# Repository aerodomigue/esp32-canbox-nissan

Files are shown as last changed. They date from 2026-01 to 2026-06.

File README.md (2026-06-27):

# ESP32 CANBox Bridge

> **Available Languages:** [Français](README.fr.md) | **English**

<p align="center">
  Assembled unit with OBD-II connector
  3D printed enclosure
</p>

<p align="center">
  Dynamic guidelines in action
  <br>
  <em>Dynamic reverse camera guidelines working with the CAN bridge</em>
</p>

This project is a **universal CAN bridge** that connects any vehicle to an Android head unit. The ESP32 reads CAN bus frames via the OBD-II port and translates them to protocols understood by Android head units (Toyota RAV4, Raise, etc.).

The project started as a custom solution for the **Nissan Juke F15**, but has since evolved into a generic, multi-vehicle platform.

**Key features:**
- **Multi-vehicle support** — Vehicle-specific CAN mappings are defined in JSON configuration files, making it easy to add support for new cars
- **Protocol translation** — Converts manufacturer-specific CAN data to head unit protocols (Toyota RAV4, Raise/RZC)
- **No recompilation needed** — Switch vehicles, adjust calibration via USB commands, or embed model-specific calibration directly in the vehicle JSON preset (`vehicleParams`)

> **Important:** In your head unit settings, configure the CAN protocol as **"Toyota RAV4"** for this to work.

> **Required App:** Use **[ESP32 CANBox Manager](https://github.com/aerodomigue/esp32-canbox-manager)** (Android) to configure, calibrate, and update the firmware via USB.

---

## Features

- **Real-time data translation** from Nissan CAN to Toyota RAV4 protocol
- **Steering wheel angle** for reverse camera guidelines
- **Dashboard data**: RPM, speed, battery voltage, temperature, fuel level
- **Door status** with automatic updates on change
- **Safety systems**: Hardware watchdog, CAN error monitoring, timeout protection

### Feature Status

| Feature | Status | Notes |
| --- | --- | --- |
| Engine RPM | ✅ Working | |
| Vehicle Speed | ✅ Working | |
| Fuel Tank Level | ✅ Working | Calibrated for Juke F15 (45L tank) |
| Battery Voltage | ✅ Working | |
| Steering / Dynamic Guidelines | ✅ Working | Calibrated for Juke F15 |
| Door Status | ✅ Working | All 4 doors + trunk |
| Indicators | ✅ Working | Left/right turn signals |
| Lights | ✅ Working | Headlights, high beam, parking lights |
| Handbrake | 📋 Planned | CAN data not yet extracted |
| External Temperature | 📋 Planned | CAN data not yet extracted |
| Instant Fuel Consumption | ✅ Working | From CAN 0x580 |
| Average Fuel Consumption | ✅ Working | From CAN 0x580 |
| Distance to Empty | ✅ Working | From CAN 0x54C |

> **Note:** Documentation for the Raise/Toyota RAV4 protocol used by Android head units is scarce. Some features are still being reverse-engineered due to lack of official protocol specifications.

See the **[Roadmap](ROADMAP.md)** for upcoming features.

---

## Hardware Requirements

### Bill of Materials (BOM)

| Component | Description | Link |
| --- | --- | --- |
| **ESP32-C3 SuperMini** | Microcontroller with native TWAI (CAN) | [AliExpress](https://fr.aliexpress.com/item/1005007479144456.html) |
| **SN65HVD230** | CAN Transceiver (3.3V) | [AliExpress](https://fr.aliexpress.com/item/1005009371955871.html) |
| **L7805CV** | 5V Voltage Regulator | [AliExpress](https://fr.aliexpress.com/item/1005005961287271.html) |
| **PCB Prototype Board** | 4x6cm perfboard | [AliExpress](https://fr.aliexpress.com/item/1005008880680070.html) |
| **Capacitor 25V 470µF** | Filtering capacitor | [AliExpress](https://fr.aliexpress.com/item/1005002075527957.html) |
| **PCB Terminal Block** | Screw terminals for wiring | [AliExpress](https://fr.aliexpress.com/item/1005006642865467.html) |
| **Fuse 1A** | Protection fuse | [AliExpress](https://fr.aliexpress.com/item/1005001756852562.html) |
| **OBD-II Plug** | CAN-H (pin 6), CAN-L (pin 14) | - |

### Power Supply Note

The ESP32 is powered via **USB from the Android head unit**.

**IMPORTANT - If using 12V power instead of USB:**
- ⚠️ **NEVER use permanent 12V** - it will drain your car battery when parked
- ✅ **Use ACC (accessory) 12V only** - it turns off with the ignition
- You'll need a voltage regulator (like the L7805CV in the BOM) to convert 12V to 5V
- ⚠️ **The current 12V circuit needs improvements**: It lacks reverse polarity protection (risk of damage if wired incorrectly) and proper noise filtering for alternator-generated electrical interference. Additional components (diode, capacitors, TVS diode) would be recommended for a robust 12V power supply.

**Why USB is recommended:**
1. **Automatic power management**: USB power from the head unit is only active when the head unit is on (ACC-controlled), preventing battery drain.
2. **Voltage stability**: Automotive 12V is unstable - it varies significantly during engine start (voltage drops), alternator charging (spikes up to 14.5V), and contains electrical noise. USB provides clean, regulated 5V power.

### Wiring Diagram

<p align="center">
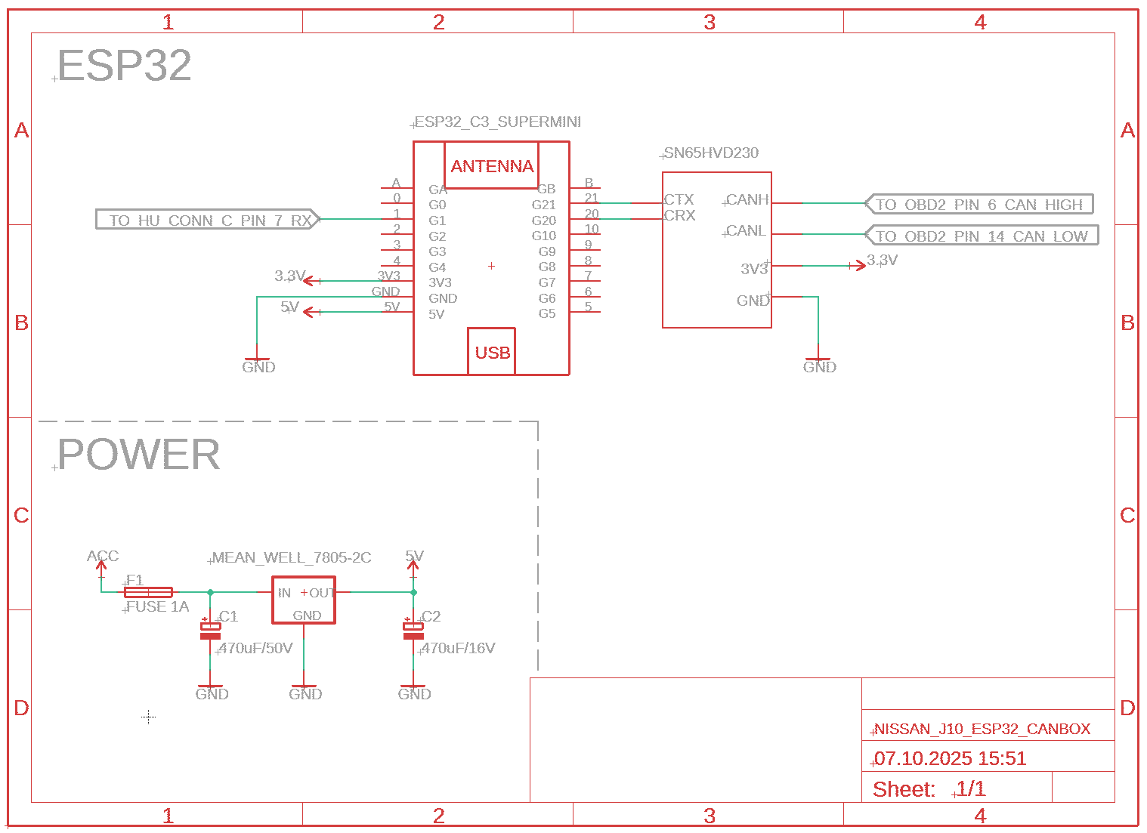
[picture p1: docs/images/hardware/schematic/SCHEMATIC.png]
Wiring schematic
  
  <br>
  <em>Schematic by Polihedron</em>
</p>

### Pinout

| Component | ESP32 Pin | Destination | Note |
| --- | --- | --- | --- |
| **SN65HVD230** | `3.3V` / `GND` | Power Supply | **Do not use 5V!** |
| | `GPIO 21` | CAN-TX | Output to CAN bus |
| | `GPIO 20` | CAN-RX | Input from CAN bus |
| **Head Unit** | `GPIO 5` (TX) | RX Wire (Radio harness) | UART 38400 baud |
| | `GPIO 6` (RX) | TX Wire (Radio harness) | Handshake responses |
| **Status LED** | `GPIO 8` | Internal LED | Visual status indicator |

### OBD-II Connection

The system connects to the vehicle via the **OBD-II diagnostic port**:

```
OBD-II Connector (looking at port)
┌─────────────────────────────┐
│  1   2   3   4   5   6   7  8  │
│                                 │
│  9  10  11  12  13  14  15  16 │
└─────────────────────────────┘

Pin 6  = CAN-H (High)
Pin 14 = CAN-L (Low)
Pin 16 = +12V Battery
Pin 4/5 = Ground
```

> **Note:** OBD-II ports have built-in termination resistors, so no additional resistor is needed on the SN65HVD230 module. If your module has a 120Ω resistor (R120), you can leave it or remove it - the bus will work either way.

### Electroheater (A/C) Connector Pinout — M25

The electroheater control unit uses connector **M25** (type TH16FW-NH, 16 pins). It carries the CAN bus and can be used as an alternative tap point.

```
Pin layout (front view):
┌─────────────────────────────────┐
│  1  2  3  4  5  6  7  8        │
│  9 10 11 12 13 14 15 16        │
└─────────────────────────────────┘
```

| Pin | Wire Color | Description |
| --- | --- | --- |
| 1 | L | **CAN-H** |
| 2 | B | Ground |
| 3 | SB | Ignition power supply |
| 4 | P | Electroheater control unit wake-up signal |
| 5 | R | Ambient temperature sensor ground |
| 9 | P | **CAN-L** |
| 10 | Y | Battery power supply |
| 12 | GR | Ambient temperature sensor signal |
| 13 | L | Ventilation system motor signal |
| 14 | Y | Electroheater relay control signal 1 |
| 15 | LG | Electroheater relay control signal 2 |
| 16 | P | Electroheater relay control signal 3 |

> Pins 6, 7, 8, 11 are not populated on this connector.

### About the Original CAN Box

The **original Raise/RZC CAN box** that came with the Android head unit is **kept installed**. It provides the **6V power supply for the reverse camera** and is still needed for that purpose.

The original box likely has CAN signal access on its connector, so it might be possible to tap the CAN bus from there instead of OBD-II. However, this was not tested - the OBD-II connection works well and is easier to install.

---

## USB Configuration (V2)

The device can be configured via USB serial without recompiling. Connect to the USB port and use a terminal at **115200 baud**.

### Available Commands

| Command | Description |
| --- | --- |
| `CFG LIST` | Show calibration parameters |
| `CFG SET <param> <value>` | Change a parameter |
| `CFG SAVE` | Save to flash (NVS) |
| `CAN STATUS` | Show CAN config status (MOCK/REAL mode) |
| `CAN LIST` | List vehicle config files |
| `CAN LOAD <file>` | Load a vehicle config |
| `CAN UPLOAD START/DATA/END` | Upload config via Base64 |
| `SYS INFO` | System information |
| `SYS DATA` | Live vehicle data |
| `HELP` | Full command list |

See **[USB Serial Protocol Documentation](docs/protocols/USB_SERIAL_PROTOCOL.md)** for complete details.

### Multi-Vehicle Support

Vehicle configurations are stored as JSON files on the device's filesystem. You can:
- Upload multiple vehicle configs (NissanJukeF15.json, ToyotaCorolla.json, etc.)
- Switch between vehicles with `CAN LOAD <file>`
- Use **Mock Mode** for testing without a vehicle

---

## Software Architecture

The system is designed to be 100% autonomous and resilient to vehicle electrical interference:

1. **[CAN Capture](docs/technical/CAN_CAPTURE.md)**: Decodes frames using JSON configuration and updates global variables
2. **[Radio Send](docs/technical/RADIO_SEND.md)**: Formats and transmits data to the head unit at multiple intervals (200ms for steering, 333ms for RPM, 500ms for speed, etc.)
3. **ConfigManager**: Persistent calibration storage (NVS). Vehicle JSON files can embed `vehicleParams` to supply model-specific defaults applied automatically on first load; user overrides via `CFG SET` are preserved across reboots on the same vehicle
4. **SerialCommand**: USB configuration interface
5. **Hardware Watchdog**: Automatic reboot if the program freezes for more than 5 seconds
6. **CAN Watchdog**: Forces reboot if no CAN data received for 30s while battery > 11V

---

## LED Status Codes

The LED (GPIO 8) provides quick diagnostics without requiring a PC connection:

| Pattern | Status | Meaning |
| --- | --- | --- |
| **Rapid flashing** | Normal | CAN data being received and processed |
| **Slow blink (500ms)** | Mock Mode | Running with simulated data |
| **Slow heartbeat (1s)** | Idle | System running, but CAN bus is silent |
| **Solid ON during boot** | Boot | System initializing |
| **No activity** | Error | System frozen or power issue |

---

## Hardware Photos

### PCB Assembly

<p align="center">
  PCB top view - components soldered
  PCB bottom view
</p>

*ESP32 with SN65HVD230 CAN transceiver soldered on perfboard*

---

## Installation & Setup

Setting up your ESP32 CANBox Bridge follows a simple two-step process:

### 1. Initial Firmware Flash
The ESP32 must be flashed with the firmware before installation. Use one of these methods:

- **Option A: Web Browser (Recommended)**
  Open **[web.esphome.io](https://web.esphome.io/)** in a Chrome-based browser.
  1. Download the **`all-firmware.bin`** from the [Latest Releases](https://github.com/aerodomigue/Nissan-canbus-headunit/releases). This single file contains the bootloader, partitions, and app.
  2. Connect your ESP32 to your computer via USB.
  3. Click **Connect**, then **Install** and select the `all-firmware.bin` file.

- **Option B: PlatformIO (Developers)**
  If you are working with the source code:
  ```bash
  pio run --target upload
  ```
  *Note: A `all-firmware.bin` is automatically generated in `.pio/build/` after each build.*

### 2. Configuration & Management
Once flashed, connect the ESP32 to your Android head unit's USB port. All further configuration is done via the companion app:

**[ESP32 CANBox Manager](https://github.com/aerodomigue/esp32-canbox-manager)** (Android App)
- **Select Vehicle**: Load the specific `.json` config for your car.
- **Calibrate**: Set steering wheel offsets and tank capacity.
- **OTA Updates**: Update future firmware versions wirelessly from the app using **`firmware.ota`**.

---

## Supported Data

| Data | CAN ID | Send Rate | Notes |
| --- | --- | --- | --- |
| Steering Angle | 0x002 | 200ms | For camera guidelines |
| Engine RPM | 0x180 | 333ms | |
| Vehicle Speed | 0x284 | 500ms | Wheel speed sensor |
| Fuel Level | 0x5C5 | — | Mapped to 45L (Juke F15 tank capacity) |
| Battery Voltage | 0x6F6 | — | Alternator output |
| Temperature | 0x551 | 5000ms | Coolant (used as exterior) |
| Door Status | 0x60D | 250ms | All doors + trunk (or on change) |
| Distance to Empty | 0x54C | 5000ms | Estimated range |
| Instant Fuel Consumption | 0x580 | 1000ms | 0.1 L/100km units |
| Average Fuel Consumption | 0x580 | 5000ms | 0.1 L/100km units |
| Odometer | 0x5C5 | 10000ms | Total km (24-bit) |

---

## Companion App

**[ESP32 CANBox Manager](https://github.com/aerodomigue/esp32-canbox-manager)** - Android app to configure and monitor the CANBox via USB.

Features:
- Live vehicle data dashboard
- CAN configuration management
- Calibration parameter tuning
- Firmware updates (OTA)
- CAN frame debugging

---

## References & Credits

### Nissan CAN Documentation
- [NICOclub / Nissan Service Manuals](https://www.nicoclub.com/nissan-service-manuals)
- [Comma.ai / OpenDBC](https://github.com/commaai/opendbc/tree/master)
- [jackm / Carhack Nissan](https://github.com/jackm/carhack/blob/master/nissan.md)
- [balrog-kun / Nissan Qashqai CAN info](https://github.com/balrog-kun/nissan-qashqai-can-info)

### Radio Protocols (Toyota/Raise/RZC)
- **[Toyota RAV4 Protocol Analysis](docs/protocols/raise-toyota-rav4/RAV4_BODY_ENGINE_2018_2020.pdf)** - Compiled and analyzed by [Mikescotland](https://forum.dudu-auto.com/u/Mikescotland) (Original Source)
- [Official Raise Protocol (Chinese)](docs/protocols/raise-toyota-rav4/) - Supplementary documentation
- [smartgauges / canbox](https://github.com/smartgauges/canbox)
- [cxsichen / Raise Protocol](https://github.com/cxsichen/helllo-world/tree/master/%E5%8D%8F%E8%AE%AE/%E7%9D%BF%E5%BF%97%E8%AF%9A)
- [DUDU-AUTO Forum / Qashqai 2011 CANbus](https://forum.dudu-auto.com/d/1786-nissan-qashqai-2011-canbus/6)

---

## License

This project is open source. See [LICENSE](LICENSE) for details.

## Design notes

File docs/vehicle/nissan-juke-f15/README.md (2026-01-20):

# Nissan Juke F15 - Documentation Technique

Documentation officielle Nissan pour le Juke F15 (Plateforme B, 2010-2019).

**Taille totale :** ~79 MB (57 fichiers PDF)

## Sources

Documentation récupérée depuis [NICOclub Nissan Service Manuals](https://www.nicoclub.com/nissan-service-manuals).

> **Note**: Ces documents sont archivés ici pour préserver l'accès en cas de fermeture du site source.

---

## Sommaire des Manuels

### 📋 Général
| Fichier | Description | Taille |
|---|---|---|
| `GI.pdf` | General Information (informations générales) | 1.5 MB |
| `DEF.pdf` | Definitions (définitions, abréviations) | 614 KB |
| `MA.pdf` | Maintenance (entretien, révisions) | 928 KB |

### 🔧 Moteur & Transmission
| Fichier | Description | Taille |
|---|---|---|
| `EM.pdf` | Engine Mechanical (moteur mécanique) | 4.5 MB |
| `EC.pdf` | Engine Control (contrôle moteur, ECU) | 5.6 MB |
| `LU.pdf` | Lubrication (lubrification) | 703 KB |
| `CO.pdf` | Cooling (refroidissement) | 928 KB |
| `EX.pdf` | Exhaust (échappement) | 328 KB |
| `EXL.pdf` | Exhaust Line (ligne d'échappement) | 1.4 MB |
| `TM.pdf` | Transmission Manual (boîte de vitesses) | 5.4 MB |
| `CL.pdf` | Clutch (embrayage) | 535 KB |

### ⚡ Électrique & Électronique
| Fichier | Description | Taille |
|---|---|---|
| `PG.pdf` | Power Generation (génération électrique, alternateur) | 4.4 MB |
| `CHG.pdf` | Charging (charge batterie) | 522 KB |
| `GW.pdf` | Gateway (passerelle réseau) | 819 KB |
| `LAN.pdf` | **LAN (CAN Bus, réseau communication)** ⭐ | 1.3 MB |
| `BCS.pdf` | **Body Control System (BCM, carrosserie)** ⭐ | 1.5 MB |

> ⭐ **Documents clés pour le projet CAN** : `LAN.pdf` et `BCS.pdf` contiennent les informations sur le bus CAN et les IDs des modules.

### 🚗 Chassis & Suspension
| Fichier | Description | Taille |
|---|---|---|
| `FAX.pdf` | Front Axle (essieu avant) | 729 KB |
| `RAX.pdf` | Rear Axle (essieu arrière) | 579 KB |
| `FSU.pdf` | Front Suspension Unit (suspension avant) | 531 KB |
| `RSU.pdf` | Rear Suspension Unit (suspension arrière) | 714 KB |
| `ST.pdf` | Suspension/Steering (suspension/direction) | 586 KB |
| `STR.pdf` | Steering (direction) | 692 KB |
| `STC.pdf` | Steering Control (contrôle direction) | 485 KB |
| `SR.pdf` | Suspension Rear (suspension arrière) | 894 KB |
| `SRC.pdf` | Suspension Rear Control (contrôle susp. arr.) | 1.3 MB |
| `FWD.pdf` | Front Wheel Drive (traction avant) | 493 KB |

### 🛑 Freinage
| Fichier | Description | Taille |
|---|---|---|
| `BR.pdf` | Brake (freinage) | 1.4 MB |
| `BRM.pdf` | Brake Manual (manuel freinage) | 4.7 MB |
| `BRC.pdf` | Brake Control (contrôle freinage, ABS) | 1.8 MB |
| `PB.pdf` | Parking Brake (frein de stationnement) | 436 KB |

### 🛡️ Sécurité
| Fichier | Description | Taille |
|---|---|---|
| `SB.pdf` | Seat Belt (ceintures de sécurité) | 571 KB |
| `PCS.pdf` | Pre-Collision System (système anti-collision) | 1.4 MB |
| `SEC.pdf` | Security (sécurité, antidémarrage) | 1.7 MB |
| `DMS.pdf` | Driver Monitoring System (surveillance conducteur) | 584 KB |

### 🚪 Carrosserie & Accès
| Fichier | Description | Taille |
|---|---|---|
| `DLK.pdf` | Door Lock (verrouillage portes) | 3.6 MB |
| `DLN.pdf` | Door Lock Network (réseau verrouillage) | 3.3 MB |
| `EXT.pdf` | Exterior (extérieur) | 1.6 MB |
| `MIR.pdf` | Mirrors (rétroviseurs) | 678 KB |
| `RF.pdf` | Roof (toit) | 817 KB |
| `WT.pdf` | Window/Trim (vitres/garnitures) | 752 KB |

### 🪟 Intérieur & Confort
| Fichier | Description | Taille |
|---|---|---|
| `INT.pdf` | Interior (intérieur) | 1.7 MB |
| `SE.pdf` | Seats (sièges) | 1.3 MB |
| `IP.pdf` | Instrument Panel (tableau de bord) | 1.4 MB |
| `INL.pdf` | Instrument Panel Lights (éclairage TB) | 801 KB |
| `HA.pdf` | HVAC (climatisation, chauffage) | 1.8 MB |
| `HAC.pdf` | HVAC Control (contrôle climatisation) | 1.9 MB |
| `CCS.pdf` | Climate Control System (système climatisation) | 199 KB |

### 💡 Éclairage & Visibilité
| Fichier | Description | Taille |
|---|---|---|
| `FL.pdf` | Front Lighting (éclairage avant) | 999 KB |
| `MWI.pdf` | Windshield Wipers (essuie-glaces) | 893 KB |
| `WW.pdf` | Windshield Washer/Wiper (lave-glace/essuie-glace) | 1.2 MB |
| `HRN.pdf` | Horn (klaxon) | 295 KB |

### 🎵 Audio & Multimédia
| Fichier | Description | Taille |
|---|---|---|
| `AV.pdf` | Audio/Visual (audio-vidéo, autoradio) | 2.5 MB |

### 🔌 Divers Électrique
| Fichier | Description | Taille |
|---|---|---|
| `ACC.pdf` | Accessory (accessoires électriques) | 232 KB |
| `PWC.pdf` | Power Control (contrôle alimentation) | 641 KB |
| `PWO.pdf` | Power Outlet (prises électriques) | 249 KB |
| `WCS.pdf` | Wiring/Communication System (câblage/réseau) | 624 KB |
| `VTL.pdf` | Vehicle Tools/Lights (outils/éclairages) | 837 KB |

---

## Utilisation pour le Projet CAN

Ces documents ont été utilisés pour :
- **Identifier les IDs CAN** et le format des trames (via `LAN.pdf`, `BCS.pdf`)
- **Mapper les signaux** du bus CAN Cabin (steering, RPM, speed, doors, fuel)
- Comprendre le **câblage du port OBD-II** (CAN-H/CAN-L pins 6/14)
- Valider les **calibrations** (réservoir 45L, diviseur RPM, offset volant)
- Localiser les **modules BCM** et leurs protocoles

### Documents Recommandés

Pour travailler sur le CAN bus, commencer par :
1. `LAN.pdf` - Architecture réseau CAN, IDs des modules
2. `BCS.pdf` - Body Control System, signaux carrosserie
3. `EC.pdf` - Engine Control, données moteur (RPM, etc.)
4. `IP.pdf` - Instrument Panel, dashboard signals

---

## Licence

Ces documents sont la propriété de **Nissan Motor Co., Ltd.** Ils sont fournis à titre de référence technique uniquement pour le reverse engineering du protocole CAN à des fins de recherche et de compatibilité avec des équipements aftermarket.

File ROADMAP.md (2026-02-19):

# Roadmap

## ✅ Completed

### v1.0 — Core Vehicle Data

| Feature | Notes |
|---|---|
| Steering / Dynamic Guidelines | Calibrated for Juke F15 |
| Engine RPM | |
| Vehicle Speed | |
| Fuel Tank Level | Calibrated 45L |
| Battery Voltage | |
| Door Status | All 4 doors + trunk |
| Handbrake | |
| Indicators | Left / Right |
| Lights | Headlights, high beam, parking |

### v1.7 — Configuration & Connectivity

| Feature | Notes |
|---|---|
| Toyota RAV4 Protocol | Migrated from VW Polo |
| NVS Persistent Storage | Calibration saved to flash |
| Serial Commands | CFG, LOG, SYS, CAN |
| JSON CAN Config | Multi-vehicle support via LittleFS |
| Mock Data Generator | Testing without vehicle |
| OTA Firmware Update | Via USB serial |
| Distance to Empty | From CAN 0x54C |
| Instant Fuel Consumption | From CAN 0x580 |
| Average Fuel Consumption | From CAN 0x580 |
| Android Companion App | [ESP32 CANBox Manager](https://github.com/aerodomigue/esp32-canbox-manager) |

---

## 🚧 Upcoming

### v1.8 — Additional Vehicle Data

| Task | Status | Notes |
|---|---|---|
| External Temperature | 🔲 | CAN data not yet extracted |
| Handbrake | 🔲 | CAN data not yet extracted |
| CAN Frame Recorder | 🔲 | For debugging |
| Steering Auto-Calibration | 🔲 | Auto-detect center offset |

> **Note:** Community Presets are managed by the [Android app](https://github.com/aerodomigue/esp32-canbox-manager) (download from GitHub or local).

### v1.9 — External CANBox Passthrough

Allow external CAN boxes (parking sensors, blind spot monitors, etc.) to communicate with the head unit through our device.

| Task | Status |
|---|---|
| Add UART2 (GPIO 2/3) | 🔲 |
| Frame parser (0x2E protocol) | 🔲 |
| TX Merge (insert between our frames) | 🔲 |
| RX Filter (forward unknown commands) | 🔲 |
| Serial commands (`PT ON/OFF/STATUS`) | 🔲 |

📄 See **[Passthrough Architecture](docs/technical/PASSTHROUGH.md)**

---

## 🏆 v2.0 — Custom PCB

The end goal: a dedicated, professional-grade board ready to use.

> **Prerequisite:** Software (ESP32 firmware + Android app) must be stable and feature-complete before starting PCB development.

### Phase 1 — Prototype

| Task | Status |
|---|---|
| Validate passthrough on perfboard | 🔲 |
| Test JST connectors | 🔲 |
| Validate 3.3V protection circuit | 🔲 |

### Phase 2 — PCB Design & Manufacturing

| Task | Status |
|---|---|
| PCB design (KiCad) | 🔲 |
| ESP32-C3 (module or chip TBD) | 🔲 |
| Integrated CAN transceiver | 🔲 |
| JST connectors (head unit, passthrough) | 🔲 |
| 3.3V pin protection | 🔲 |
| USB-C power (from head unit) | 🔲 |
| Boot/Reset buttons | 🔲 |
| Compact form factor | 🔲 |
| 3D printed enclosure | 🔲 |
| PCBA manufacturing | 🔲 |

> **Goal:** One-click order via shared JLCPCB project link (Gerbers + BOM + assembly).

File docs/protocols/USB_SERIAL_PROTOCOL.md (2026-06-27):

# USB Serial Protocol Documentation

## Overview

The ESP32 CANBox exposes a USB CDC (Communications Device Class) serial interface for configuration and monitoring. This document describes the command protocol for Android app integration.

## Connection Parameters

| Parameter | Value |
|---|---|
| Baud Rate | 115200 |
| Data Bits | 8 |
| Parity | None |
| Stop Bits | 1 |
| Flow Control | None |
| Line Ending | `\n` (LF) or `\r\n` (CRLF) |

## Command Format

Commands follow an AT-style format:
```
COMMAND [SUBCOMMAND] [PARAMETERS]\n
```

- Commands are **case-insensitive** (converted to uppercase internally)
- Parameters are separated by spaces
- Responses always start with `OK` or `ERROR:`
- Multi-line responses are delimited by `===` markers

## Response Format

### Success Response
```
OK
[optional additional info]
```

### Error Response
```
ERROR: <error description>
```

---

## Command Reference

### CFG - Calibration Parameters (NVS Storage)

Manages calibration values stored in ESP32's Non-Volatile Storage (NVS).

#### CFG GET `<param>`
Read a calibration parameter value.

```
> CFG GET steerOffset
steerOffset = 100
```

#### CFG SET `<param>` `<value>`
Set a calibration parameter (in memory only).

```
> CFG SET steerOffset 150
OK
Value set (use CFG SAVE to persist)
```

#### CFG LIST
Display all calibration parameters.

```
> CFG LIST
=== Current Configuration ===
steerOffset  = 100    (center offset)
steerInvert  = 1      (invert direction)
steerScale   = 300    (scale x0.0001)
indTimeout   = 500    (indicator ms)
rpmDiv       = 7      (RPM divisor)
tankCap      = 45     (tank liters)
dteDiv       = 283    (DTE divisor x100)
=============================
```

#### CFG SAVE
Persist current values to NVS flash.

```
> CFG SAVE
OK
Configuration saved to NVS
```

#### CFG RESET
Reset all values to factory defaults.

```
> CFG RESET
OK
Configuration reset to defaults
```

#### Available Parameters

| Parameter | Type | Range | Default | Description |
|---|---|---|---|---|
| `steerOffset` | int16 | -500 to +500 | 100 | Steering center offset |
| `steerInvert` | bool | 0/1 | 1 | Invert steering direction |
| `steerScale` | uint16 | 1-20000 | 300 | Scale factor (x0.0001). e.g. 200 = 0.0200x |
| `indTimeout` | uint16 | 100-2000 | 500 | Indicator timeout (ms) |
| `rpmDiv` | uint8 | 1-20 | 7 | RPM divisor |
| `tankCap` | uint8 | 20-100 | 45 | Tank capacity (liters) |
| `dteDiv` | uint16 | 100-500 | 283 | DTE divisor (x100) |

---

### CAN - CAN Configuration Files (LittleFS Storage)

Manages vehicle CAN configuration files stored on LittleFS filesystem.

#### CAN STATUS
Display current CAN configuration status.

```
> CAN STATUS
=== CAN Configuration Status ===
Mode: REAL (CAN bus)
Profile: Nissan Juke F15
Frames processed: 12345
Unknown frames: 67
================================
```

#### CAN LIST
List all JSON config files on filesystem.

```
> CAN LIST
=== CAN Config Files ===
  NissanJukeF15.json (2048 bytes)
  MockDemo.json (512 bytes)
Total: 2 file(s)
========================
```

#### CAN LOAD `<filename>`
Load and activate a specific config file.

```
> CAN LOAD NissanJukeF15.json
OK
Loaded: Nissan Juke F15
Mode: REAL
```

#### CAN GET
Output the current active config file as JSON.

```
> CAN GET
=== BEGIN JSON ===
{
  "name": "Nissan Juke F15",
  "isMock": false,
  "frames": [...]
}
=== END JSON ===
```

#### CAN DELETE `<filename>`
Delete a config file from filesystem.

```
> CAN DELETE OldConfig.json
OK
Deleted: /OldConfig.json
```

#### CAN RELOAD
Reload configuration (searches for /vehicle.json or /NissanJukeF15.json).

```
> CAN RELOAD
Reloading CAN configuration...
OK
Loaded: Nissan Juke F15 (REAL mode)
```

---

### CAN UPLOAD - File Upload Protocol

Upload a new CAN configuration file using base64-encoded chunks.

#### Protocol Sequence

```
┌─────────────┐                              ┌─────────────┐
│   Android   │                              │    ESP32    │
│     App     │                              │   CANBox    │
└──────┬──────┘                              └──────┬──────┘
       │                                            │
       │  CAN UPLOAD START <filename> <size>        │
       │───────────────────────────────────────────>│
       │                                            │
       │  OK READY                                  │
       │<───────────────────────────────────────────│
       │  Awaiting <size> bytes for <filename>      │
       │                                            │
       │  CAN UPLOAD DATA <base64_chunk_1>          │
       │───────────────────────────────────────────>│
       │                                            │
       │  OK 128/1024                               │
       │<───────────────────────────────────────────│
       │                                            │
       │  CAN UPLOAD DATA <base64_chunk_2>          │
       │───────────────────────────────────────────>│
       │                                            │
       │  OK 256/1024                               │
       │<───────────────────────────────────────────│
       │                                            │
       │  ... (repeat until all data sent)          │
       │                                            │
       │  CAN UPLOAD END                            │
       │───────────────────────────────────────────>│
       │                                            │
       │  OK                                        │
       │<───────────────────────────────────────────│
       │  Saved: /vehicle.json (1024 bytes)         │
       │  Use 'CAN RELOAD' to activate              │
       │                                            │
```

#### CAN UPLOAD START `<filename>` `<size>`
Begin a new upload session.

- `filename`: Target filename (with or without leading `/`)
- `size`: Exact size in bytes of the **raw JSON** (before base64 encoding)

```
> CAN UPLOAD START vehicle.json 2048
OK READY
Awaiting 2048 bytes for /vehicle.json
```

**Limits:**
- Maximum file size: 8192 bytes (8KB)
- Filename must end with `.json`

#### CAN UPLOAD DATA `<base64_data>`
Send a chunk of base64-encoded data.

```
> CAN UPLOAD DATA eyJuYW1lIjoiTmlzc2FuIEp1a2UgRjE1IiwiaXNNb2NrIjpmYWxzZSwiZnJhbWVzIjpb...
OK 256/2048
```

**Chunk Size Recommendations:**
- Recommended chunk size: 128-192 bytes of raw data
- Base64 expands data by ~33% (128 bytes → 172 base64 chars)
- Max command line: 256 characters (including `CAN UPLOAD DATA `)

#### CAN UPLOAD END
Finalize the upload and validate JSON.

```
> CAN UPLOAD END
OK
Saved: /vehicle.json (2048 bytes)
Use 'CAN RELOAD' to activate
```

**Validation Checks:**
1. JSON syntax valid
2. Required fields present: `name`, `frames`
3. File written successfully to LittleFS

#### CAN UPLOAD ABORT
Cancel an in-progress upload.

```
> CAN UPLOAD ABORT
Upload aborted
```

---

### OTA - Firmware Updates

Update the device firmware over USB serial using base64-encoded chunks.

> **Full specification:** see [`docs/protocols/OTA_PROTOCOL.md`](OTA_PROTOCOL.md)

#### Protocol Sequence (v2)

```
┌─────────────┐                              ┌─────────────┐
│   Android   │                              │    ESP32    │
│     App     │                              │   CANBox    │
└──────┬──────┘                              └──────┬──────┘
       │                                            │
       │  OTA ABORT          (pre-flight)           │
       │───────────────────────────────────────────>│
       │  OTA aborted  (drain 1s)                   │
       │                                            │
       │  OTA START <size> [md5]                    │
       │───────────────────────────────────────────>│
       │                                            │
       │  OTA starting: expecting <size> bytes      │  ← info lines first
       │<───────────────────────────────────────────│
       │  MD5: <md5>                                │
       │<───────────────────────────────────────────│
       │  OK READY                                  │  ← terminal line (last)
       │<───────────────────────────────────────────│
       │                                            │
       │  OTA DATA <base64> <crc32>                 │  ← no echo from ESP32
       │───────────────────────────────────────────>│
       │                                            │
       │  OK 180/413648 (0%)                        │
       │<───────────────────────────────────────────│
       │                                            │
       │  ... (repeat until 100%)                   │
       │                                            │
       │  OTA END                                   │
       │───────────────────────────────────────────>│
       │                                            │
       │  MD5 verified OK                           │
       │<───────────────────────────────────────────│
       │  OK                                        │
       │<───────────────────────────────────────────│
       │                                            │
       ▼         [Device reboots ~2s later]         ▼
```

#### OTA START `<size>` `[md5]`

```
> OTA START 413648 a1b2c3d4e5f6789012345678abcdef01
OTA starting: expecting 413648 bytes
MD5: a1b2c3d4e5f6789012345678abcdef01
OK READY
```

Note: info lines come **before** `OK READY` (v2 change). Parse by scanning for the `OK` prefix.

#### OTA DATA `<base64_data>` `[crc32_hex]`

```
> OTA DATA UjBsR09EbGhBUUFCQUlBQUFBQUFBUC8vL3lINUJBRUFBQUFBTEFBQUFBQUJBQUVBQUFJQlJBQTc= a1b2c3d4
OK 180/413648 (0%)
```

CRC32 is the hex checksum of the **decoded binary** chunk (not the base64 string).
On CRC mismatch, the device returns `ERROR: CRC mismatch chunk ...` without aborting OTA — the same chunk can be retransmitted safely.

Auto-abort: if no `OTA DATA` is received for **60 seconds**, OTA is aborted automatically.

#### OTA END / OTA ABORT / OTA STATUS

Unchanged from v1. See [`docs/protocols/OTA_PROTOCOL.md`](OTA_PROTOCOL.md) for full details.

---

### LOG - CAN Frame Logging

Enable/disable real-time CAN frame logging for debugging.

#### LOG ON
```
> LOG ON
OK
CAN logging enabled
```

After enabling, each received CAN frame is printed:
```
RX 0x002 [8]: 00 0B 60 00 00 00 00 00
RX 0x180 [8]: 45 E0 00 00 00 00 00 00
```

#### LOG OFF
```
> LOG OFF
OK
CAN logging disabled
```

---

### SYS - System Information & Control

#### SYS INFO
Display system information.

```
> SYS INFO
=== System Info ===
Firmware: 1.7.2 (2026-01-28)
Uptime: 3600 sec
Free heap: 245000 bytes
CPU freq: 160 MHz
Chip: ESP32-C3 rev3
===================
```

#### SYS DATA
Display current vehicle data values.

```
> SYS DATA
=== Live Vehicle Data ===
RPM:      2500
Speed:    60 km/h
Steering: -150
Fuel:     30 L
Battery:  14.1 V
DTE:      350 km
Temp:     85 C
Doors:    0x00
Lights:   H=1 P=0 HB=0 L=0 R=0
=========================
```

#### SYS REBOOT
Restart the device.

```
> SYS REBOOT
Rebooting...
```

#### SYS BOOTLOADER
Enter esptool bootloader mode for fast firmware flashing.

```
> SYS BOOTLOADER
Entering bootloader mode for esptool...
Use esptool.py to flash firmware.
```

After this command, the device restarts in download mode. Use `esptool.py` or an Android app implementing the esptool protocol to flash firmware at high speed (~100+ KB/s).

**Note:** This is the recommended method for firmware updates. The OTA serial commands (base64) are provided as a fallback.

---

### HELP
Display command summary.

```
> HELP
=== ESP32 CANBox Command Interface ===

CFG GET <param>       Read calibration value
CFG SET <param> <val> Set calibration value
CFG LIST              Show all calibration
CFG SAVE              Save to flash (NVS)
CFG RESET             Reset to defaults

CAN STATUS            CAN config status
CAN LIST              List config files
CAN LOAD <file>       Load config file
CAN GET               Output current config
CAN DELETE <file>     Delete config file
CAN UPLOAD START/DATA/END  Upload config
CAN RELOAD            Reload configuration

OTA START <size> [md5]  Start firmware update
OTA DATA <base64>       Send firmware chunk
OTA END                 Finalize update
OTA ABORT               Cancel update
OTA STATUS              Show OTA status

LOG ON|OFF            CAN frame logging

SYS INFO              System information
SYS DATA              Live vehicle data
SYS REBOOT            Restart device
SYS BOOTLOADER        Enter esptool flash mode

HELP                  This message
======================================
```

---

## Android Integration Example (Kotlin)

```kotlin
class CanBoxSerial(private val usbConnection: UsbDeviceConnection) {

    private val inputStream: InputStream
    private val outputStream: OutputStream

    fun sendCommand(command: String): String {
        outputStream.write("$command\n".toByteArray())
        outputStream.flush()

        // Read response until OK or ERROR
        val response = StringBuilder()
        val reader = BufferedReader(InputStreamReader(inputStream))
        var line: String?
        while (reader.readLine().also { line = it } != null) {
            response.appendLine(line)
            if (line!!.startsWith("OK") || line!!.startsWith("ERROR:")) {
                break
            }
        }
        return response.toString()
    }

    fun uploadConfig(filename: String, jsonContent: String): Boolean {
        val bytes = jsonContent.toByteArray(Charsets.UTF_8)

        // Start upload
        var response = sendCommand("CAN UPLOAD START $filename ${bytes.size}")
        if (!response.contains("OK READY")) {
            return false
        }

        // Send data in chunks (128 bytes raw = ~172 base64 chars)
        val chunkSize = 128
        var offset = 0
        while (offset < bytes.size) {
            val end = minOf(offset + chunkSize, bytes.size)
            val chunk = bytes.copyOfRange(offset, end)
            val base64 = Base64.encodeToString(chunk, Base64.NO_WRAP)

            response = sendCommand("CAN UPLOAD DATA $base64")
            if (!response.startsWith("OK")) {
                sendCommand("CAN UPLOAD ABORT")
                return false
            }
            offset = end
        }

        // Finalize
        response = sendCommand("CAN UPLOAD END")
        return response.startsWith("OK")
    }

    fun getStatus(): CanStatus {
        val response = sendCommand("CAN STATUS")
        // Parse response...
        return CanStatus(...)
    }
}
```

---

## Error Handling

| Error Message | Cause | Resolution |
|---|---|---|
| `Unknown command` | Invalid command name | Check spelling, use HELP |
| `Unknown parameter` | Invalid CFG parameter | Use CFG LIST to see valid params |
| `Value must be X to Y` | Value out of range | Check parameter limits |
| `No upload in progress` | UPLOAD DATA/END without START | Send UPLOAD START first |
| `Invalid size (max 8KB)` | File too large | Reduce config file size |
| `Out of memory` | Heap exhausted | Reduce file size, reboot device |
| `Base64 decode failed` | Corrupted data chunk | Resend chunk or abort |
| `JSON parse failed` | Invalid JSON syntax | Validate JSON before upload |
| `Invalid config: missing 'name' or 'frames'` | Required fields missing | Add name and frames to JSON |
| `File not found` | File doesn't exist | Check filename with CAN LIST |
| `Failed to create file` | Filesystem error | Check LittleFS space |
| `OTA already in progress` | START sent twice | Send OTA ABORT first |
| `Firmware too large` | Size exceeds free space | Check OTA STATUS for available space |
| `OTA not started` | DATA/END without START | Send OTA START first |
| `OTA write failed` | Flash write error | Abort and retry, check device health |
| `MD5 mismatch!` | Firmware corrupted | Re-download firmware and retry |
| `Not enough data received` | Incomplete transfer | Resend missing chunks |

---

## Version History

| Version | Date | Changes |
|---|---|---|
| 1.7.2 | 2026-01-28 | Added SYS BOOTLOADER, fuel consumption, DTE commands |
| 1.7.0 | 2026-01-26 | Added OTA firmware update commands |
| 1.6.0 | 2026-01-26 | Added CAN config upload commands |
| 1.5.0 | 2026-01-22 | Initial serial command interface |

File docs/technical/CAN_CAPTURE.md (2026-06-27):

# CAN Capture - Technical Documentation

This module handles passive listening on the vehicle **High Speed CAN bus** (Cabin network). It delegates frame processing to the `CanConfigProcessor`, which uses JSON configuration files to decode binary vehicle frames into normalized variables.

---

## Physical Specifications

| Parameter | Value |
| --- | --- |
| **Bus Speed** | 500 kbps |
| **ID Format** | 11-bit (Standard CAN 2.0A) |
| **Wiring** | Twisted pair (CAN-H / CAN-L) |
| **Access Point** | OBD-II port: Pin 6 (CAN-H), Pin 14 (CAN-L) |

---

## Architecture

Since v1.6, CAN frame decoding is **fully configurable via JSON files**. The `CanCapture.cpp` module is a thin wrapper that:

1. Receives CAN frames from the TWAI driver
2. Delegates processing to `CanConfigProcessor.processFrame()`
3. Toggles the LED on steering frame (0x002) for activity indication
4. Logs frames to serial if `LOG ON` is active

The actual decoding logic (byte extraction, formulas, target mapping) is defined in JSON configuration files stored on LittleFS. See [Vehicle Preset Guide](../VEHICLE_PRESET_GUIDE.md) for the JSON format.

---

## Decoded CAN Frames (Nissan Juke F15)

The following table describes the CAN frames decoded by the default `NissanJukeF15.json` configuration:

### 1. Steering & Dynamics

| CAN ID | Signal | Bytes | Formula | Unit | Notes |
| --- | --- | --- | --- | --- | --- |
| **0x002** | Steering Angle | [1-2] | NONE (raw INT16) | 0.1° | Signed, Big Endian. Center offset applied by ConfigManager |
| **0x180** | Engine RPM | [0-1] | SCALE [1, 7, 0] | RPM | `raw / 7` |
| **0x284** | Vehicle Speed | [0-1] | SCALE [1, 100, 0] | km/h | `raw / 100` (wheel speed sensor) |

### 2. Instrument Cluster (CAN ID 0x5C5)

| Byte | Signal | Formula | Notes |
| --- | --- | --- | --- |
| **[0]** | Fuel Level | MAP_RANGE [255, 0, 0, 45] | Inverted scale (255=empty, 0=full) mapped to 0-45L |
| **[1-3]** | Odometer | NONE (UINT24) | Total km (24-bit Big Endian) |

### 3. Power Management

| CAN ID | Signal | Bytes | Formula | Unit | Notes |
| --- | --- | --- | --- | --- | --- |
| **0x6F6** | Battery Voltage | [0] | NONE (UINT8) | 0.1V | Raw value in decivolts (e.g., 141 = 14.1V). Converted to float by `writeToGlobalData()` |
| **0x551** | Coolant Temp | [0] | SCALE [1, 1, -40] | °C | Used as exterior temp substitute |

### 4. Body Control Module (CAN ID 0x60D)

Bytes [0-2] form a **24-bit status word** (Big Endian BITMASK). Individual bits are extracted using `BITMASK_EXTRACT`:

| Bit | Mask (decimal) | Signal | Notes |
| --- | --- | --- | --- |
| 11 | 2048 | High Beam | 1 = on |
| 13 | 8192 | Left Indicator | Pulse when active |
| 14 | 16384 | Right Indicator | Pulse when active |
| 17 | 131072 | Headlights (low beam) | 1 = on |
| 18 | 262144 | Parking Lights | 1 = on |
| 19 | 524288 | Passenger Door | 1 = open |
| 20 | 1048576 | Driver Door | 1 = open |
| 21 | 2097152 | Rear Left Door | 1 = open |
| 22 | 4194304 | Rear Right Door | 1 = open |
| 23 | 8388608 | Boot/Trunk | 1 = open |

**Indicator Detection:**
- Indicators pulse on CAN only when the blinker relay is active
- A configurable timeout (default 500ms) is used to detect if indicator is currently blinking
- Timestamps are recorded for each pulse to track indicator state

**Output Mapping:**

*Doors* → `currentDoors` bitmask (Toyota RAV4 format):
- Bit 20 (Driver) → 0x80
- Bit 19 (Passenger) → 0x40
- Bit 21 (Rear Left) → 0x20
- Bit 22 (Rear Right) → 0x10
- Bit 23 (Boot) → 0x08

*Lights* → Individual boolean variables:
- `headlightsOn`, `highBeamOn`, `parkingLightsOn`
- `lastLeftIndicatorTime`, `lastRightIndicatorTime` (timestamps)

### 5. Trip Computer (CAN ID 0x54C)

| Byte | Signal | Formula | Notes |
| --- | --- | --- | --- |
| **[6-7]** | Distance to Empty | SCALE [100, 283, 0] | `raw * 100 / 283` → estimated range in km |

### 6. Fuel Consumption (CAN ID 0x580)

| Byte | Signal | Formula | Notes |
| --- | --- | --- | --- |
| **[2]** | Instant. Consumption | BITMASK_EXTRACT [127, 0] | Mask 0x7F, 0.1 L/100km units |
| **[4]** | Average Consumption | NONE (UINT8) | 0.1 L/100km units |

---

## Software Implementation

The capture relies on the **ESP32-TWAI-CAN** library.

### Boot Initialisation

Before any CAN frame is processed, `CanConfigProcessor::begin()` runs once during `setup()`:

```
1. LittleFS mounted
2. Vehicle JSON file located (NVS → /vehicle.json → /NissanJukeF15.json)
3. JSON parsed: name, isMock, vehicleParams, frames
4. Vehicle switch detection:
   ├─ Same file as previously loaded → NVS calibration preserved, vehicleParams skipped
   └─ Different file (or first boot) → configReset() → vehicleParams applied → configSave()
5. CAN frame processing begins
```

The `vehicleParams` section in the JSON file allows a preset to carry its own calibration defaults (steering scale, offsets, tank capacity, etc.). These override NVS on vehicle switch but never overwrite user customisations made via `CFG SET` on the same vehicle. See [Vehicle Parameters](../VEHICLE_PRESET_GUIDE.md#vehicle-parameters-vehicleparams) for the full key reference.

### Processing Pipeline

```
CAN Frame received
       │
       ▼
CanCapture.handleCanCapture()
       │
       ├─► CanConfigProcessor.processFrame()
       │       │
       │       ├─► findFrameConfig(canId)     → lookup JSON config
       │       ├─► extractRawValue()           → read bytes (BE/LE)
       │       ├─► applyFormula()              → SCALE / MAP_RANGE / BITMASK
       │       └─► writeToGlobalData()         → update global variables
       │
       ├─► LED toggle on 0x002 (heartbeat)
       │
       └─► Serial log if LOG ON
```

### Activity Monitoring

- **Heartbeat**: The steering frame (0x002) is continuously emitted by the power steering system. The LED on GPIO 8 toggles on each reception, confirming that the SN65HVD230 transceiver is working properly.

### Non-blocking Design

- The `handleCanCapture()` function processes one frame at a time to avoid blocking the main loop.
- All decoded values are stored in global variables (defined in `GlobalData.cpp`) for access by the radio transmission module.

### Debug Logging

When CAN logging is enabled (`LOG ON` via serial), the system outputs each received CAN frame:

```
RX 0x180 [8]: 00 00 45 6A 7A 00 32 10
RX 0x284 [8]: 00 00 00 2D 00 00 D6 5C
RX 0x60D [8]: 08 06 00 00 00 00 00 00
```

---

## Data Flow

```
┌─────────────┐      ┌──────────────────┐      ┌──────────────┐      ┌─────────────┐
│  Vehicle     │ CAN  │  CanCapture      │      │  CanConfig   │ Vars │  RadioSend  │
│  ECUs        │ ───► │  (thin wrapper)  │ ───► │  Processor   │ ───► │  Module     │
└─────────────┘      └──────────────────┘      └──────────────┘      └─────────────┘
     0x002                                       JSON config           Reads global
     0x180            Delegates to               defines how           variables
     0x284            processor                  to decode             Sends to radio
     0x5C5                                       each frame
     0x551
     0x60D            Output variables:
     0x6F6            currentSteer, engineRPM, vehicleSpeed,
     0x54C            fuelLevel, currentOdo, voltBat, tempExt,
     0x580            currentDoors, headlightsOn, highBeamOn,
                      parkingLightsOn, dteValue,
                      fuelConsumptionInst, fuelConsumptionAvg,
                      lastLeftIndicatorTime, lastRightIndicatorTime
```

---

## References

### Nissan CAN Reverse Engineering
- [NICOclub / Nissan Service Manuals](https://www.nicoclub.com/nissan-service-manuals)
- [Comma.ai / OpenDBC](https://github.com/commaai/opendbc/tree/master)
- [jackm / Carhack Nissan](https://github.com/jackm/carhack/blob/master/nissan.md)
- [balrog-kun / Nissan Qashqai CAN info](https://github.com/balrog-kun/nissan-qashqai-can-info)

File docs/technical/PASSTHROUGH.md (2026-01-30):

# External CANBox Passthrough

Allow external CAN boxes (parking sensors, blind spot monitors, etc.) to communicate with the Android head unit through our ESP32 device.

---

## Overview

Many aftermarket CAN boxes use the same **Raise/Toyota protocol** (0x2E frames @ 38400 baud). Instead of connecting them directly to the head unit (which would conflict with our device), we act as a **smart multiplexer**.

**How it works:**
- ESP32 sends Nissan vehicle data (translated to Toyota protocol)
- External device sends its own data (parking sensors, etc.)
- Both streams are **merged** before reaching the head unit
- Head unit commands: **FILTER** mode (consume or forward) or **DUPLICATE** mode (process and forward)

---

## Architecture

```
┌────────────────┐                                         ┌────────────────┐
│    External    │                                         │    Android     │
│    CANBox      │         ┌───────────────────┐           │    Head Unit   │
│                │         │     ESP32-C3      │           │                │
│  (parking      │   TX    │                   │   TX      │                │
│   sensors,     │────────▶│  ┌─────────────┐  │──────────▶│                │
│   BSD, etc.)   │  GPIO2  │  │    MERGE    │  │  GPIO5    │                │
│                │         │  │             │  │           │                │
│                │   RX    │  │  ESP32 data │  │   RX      │                │
│                │◀────────│  │      +      │  │◀──────────│                │
│                │  GPIO3  │  │  Ext. data  │  │  GPIO6    │                │
└────────────────┘         │  └─────────────┘  │           └────────────────┘
                           │                   │
                           │  ┌─────────────┐  │
                           │  │   FILTER    │  │
                           │  │             │  │
                           │  │ known → use │  │
                           │  │ unknown →   │  │
                           │  │   forward   │  │
                           │  └─────────────┘  │
                           └───────────────────┘
```

---

## Data Flow

### TX → Head Unit

| Source | Behavior |
|---|---|
| ESP32 | Send our frames (RPM, speed, steering, doors...) |
| External | Buffer complete frames, insert between ours |

> **Merge Logic:** After each transmission, check if external device has a complete frame ready. If yes, send it. No byte interleaving.

### RX ← Head Unit

Two modes available (configurable via app):

**FILTER mode** (default)

| Command | Action |
|---|---|
| `0x81` Start/End | Consume only |
| `0x90` Request | Forward only |
| `0xA0` Amp control | Forward only |
| `0xC0-C4` Source/Media | Forward only |
| `0xC6` Radar volume | Forward only |
| Unknown | Forward only |

**DUPLICATE mode**

| Command | Action |
|---|---|
| All | Process AND forward |

> In DUPLICATE mode, ESP32 handles commands it knows AND forwards everything to the external device. Useful when external device needs to see all traffic.

---

## Protocol

All devices use the same frame format:

```
┌────────┬─────────┬────────┬──────────────┬──────────┐
│  0x2E  │ Command │ Length │  Payload[n]  │ Checksum │
│ header │   1B    │   1B   │   Length B   │    1B    │
└────────┴─────────┴────────┴──────────────┴──────────┘

Checksum = (Command + Length + Σ Payload) XOR 0xFF
```

---

## Hardware

### Pinout

| Function | GPIO | Dir |
|---|---|-----|
| External RX (from device) | 2 | IN |
| External TX (to device) | 3 | OUT |
| Radio TX (to head unit) | 5 | OUT |
| Radio RX (from head unit) | 6 | IN |

### Wiring

```
External CANBox              ESP32-C3
┌──────────────┐            ┌──────────────┐
│          TX ─┼────────────┼─▶ GPIO 2     │
│          RX ◀┼────────────┼── GPIO 3     │
│         GND ─┼────────────┼── GND        │
└──────────────┘            └──────────────┘
```

> ⚠️ External device must use **3.3V logic**. If 5V, add a voltage divider on RX.

---

## Implementation

### Frame Buffering

```cpp
uint8_t extBuffer[64];       // Frame being received
uint8_t extBufferLen = 0;
uint8_t extExpectedLen = 0;

uint8_t extReadyFrame[64];   // Complete frame ready to send
uint8_t extReadyLen = 0;
bool extFrameReady = false;
```

### Parser State Machine

1. Wait for `0x2E` header
2. Read command byte
3. Read length byte
4. Read `length` payload bytes
5. Read checksum byte
6. Validate → copy to ready buffer

### Merge Timing

```cpp
void processRadioUpdates() {
    sendSteeringAngleMessage(...);
    sendExternalFrameIfReady();    // ← insert here

    sendDoorCommand(...);
    sendExternalFrameIfReady();    // ← and here

    sendRpmMessage(...);
    sendExternalFrameIfReady();    // ← etc.
}
```

---

## Commands

| Command | Description |
|---|---|
| `PT ON` | Enable passthrough |
| `PT OFF` | Disable passthrough |
| `PT STATUS` | Show status and stats |
| `PT MODE FILTER` | Set FILTER mode (default) |
| `PT MODE DUPLICATE` | Set DUPLICATE mode |

---

## Limitations

- Uses **SoftwareSerial** (ESP32-C3 has only 2 hardware UARTs)
- Max baud: **38400** (same as head unit protocol)
- **Single** external device (no daisy-chain)
- External device must not flood faster than merge rate

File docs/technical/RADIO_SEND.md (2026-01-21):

# Radio Send - Technical Documentation

The `RadioSend.cpp` module communicates with the Android head unit MCU via the **Toyota RAV4 / Raise protocol** over UART.

## Commands Summary

| Command | Name | Length | Update Rate |
| --- | --- | --- | --- |
| 0x21 | Trip Info (Avg Speed, Time, Range) | 7 | 5000ms |
| 0x22 | Instantaneous Fuel Consumption | 3 | 1000ms |
| 0x23 | Average Fuel Consumption | 3 | 5000ms |
| 0x24 | Door Status | 1 | 250ms |
| 0x28 | Outside Temperature | 12 | 5000ms |
| 0x29 | Steering Wheel Angle | 2 | 200ms |
| 0x7D/01 | Lights & Indicators | 2 | 200ms |
| 0x7D/03 | Vehicle Speed | 5 | 500ms |
| 0x7D/04 | Odometer | 12 | 10000ms |
| 0x7D/0A | Engine RPM | 3 | 333ms |

---

## Serial Specifications

| Parameter | Value |
| --- | --- |
| **Baud Rate** | 38400 bps |
| **Format** | 8N1 (8 data bits, No parity, 1 Stop bit) |
| **TX Pin** | GPIO 5 (ESP32 → Radio RX) |
| **RX Pin** | GPIO 6 (Radio TX → ESP32) |

---

## Protocol Frame Format

All frames follow this structure:

```
┌────────┬─────────┬────────┬──────────────┬──────────┐
│ Header │ Command │ Length │ Payload[n]   │ Checksum │
│  0x2E  │  (1B)   │  (1B)  │ (Length B)   │   (1B)   │
└────────┴─────────┴────────┴──────────────┴──────────┘
```

### Checksum Calculation

```
Checksum = (Command + Length + Sum(Payload bytes)) XOR 0xFF
```

---

## Implemented Commands

### 1. Steering Wheel Angle (Command 0x29)

| Field | Value |
| --- | --- |
| **Update Rate** | 200ms |
| **Payload Length** | 2 bytes |
| **Format** | Little Endian signed 16-bit |
| **Unit** | degrees |

**Payload Structure:**
```
Byte 0: Angle LSB
Byte 1: Angle MSB
```

**Notes:**
- Range: -540 to +540 (full lock to full lock)
- Sign is inverted from Nissan to match Toyota convention
- Used for reverse camera dynamic guidelines

---

### 2. Door Status (Command 0x24)

| Field | Value |
| --- | --- |
| **Update Rate** | 250ms or on change |
| **Payload Length** | 1 byte |

**Payload Structure:**
```
Byte 0: Door status bitmask
```

**Status Bitmask:**
| Bit | Meaning | Values |
| --- | --- | --- |
| 7 | Driver door (Front Left) | 0=closed, 1=open |
| 6 | Passenger door (Front Right) | 0=closed, 1=open |
| 5 | Rear Right door | 0=closed, 1=open |
| 4 | Rear Left door | 0=closed, 1=open |
| 3 | Trunk/Boot | 0=closed, 1=open |

---

### 3. Multi-Function Command (Command 0x7D)

The multi-function command uses sub-commands for different data types.

#### 3.1 Lights & Indicators (Sub-command 0x01)

| Field | Value |
| --- | --- |
| **Update Rate** | 200ms or on change |
| **Payload Length** | 2 bytes |

**Payload Structure:**
```
Byte 0: Sub-command (0x01)
Byte 1: Lights bitmask
```

**Lights Bitmask:**
| Bit | Hex | Meaning |
| --- | --- | --- |
| 7 | 0x80 | Parking lights |
| 6 | 0x40 | Headlights (low beam) |
| 5 | 0x20 | High beam |
| 4 | 0x10 | Left indicator |
| 3 | 0x08 | Right indicator |

**Notes:**
- Indicators use timeout detection (500ms) since CAN only signals when active
- Multiple lights can be active simultaneously (OR'd together)

**Example:** Headlights + Left indicator → 0x40 | 0x10 = 0x50

---

#### 3.2 Engine RPM (Sub-command 0x0A)

| Field | Value |
| --- | --- |
| **Update Rate** | 333ms (~3 Hz) |
| **Payload Length** | 3 bytes |

**Payload Structure:**
```
Byte 0: Sub-command (0x0A)
Byte 1: RPM × 4 LSB
Byte 2: RPM × 4 MSB
```

**Example:** 2500 RPM → 2500 × 4 = 10000 → 0x10, 0x27

---

#### 3.3 Vehicle Speed (Sub-command 0x03)

| Field | Value |
| --- | --- |
| **Update Rate** | 500ms |
| **Payload Length** | 5 bytes |

**Payload Structure:**
```
Byte 0: Sub-command (0x03)
Byte 1: Speed × 100 LSB
Byte 2: Speed × 100 MSB
Byte 3: 0x00 (reserved)
Byte 4: 0x00 (reserved)
```

**Example:** 45 km/h → 45 × 100 = 4500 → 0x94, 0x11

---

#### 3.4 Odometer (Sub-command 0x04)

| Field | Value |
| --- | --- |
| **Update Rate** | 10000ms (10 seconds) |
| **Payload Length** | 12 bytes |

**Payload Structure:**
```
Byte 0: Sub-command (0x04)
Byte 1: Odometer LSB
Byte 2: Odometer Middle byte
Byte 3: Odometer MSB
Bytes 4-11: 0x00 (reserved)
```

---

### 4. Outside Temperature (Command 0x28)

| Field | Value |
| --- | --- |
| **Update Rate** | 5000ms (optional) |
| **Payload Length** | 12 bytes |

**Payload Structure:**
```
Bytes 0-4: 0x00 (reserved)
Byte 5: Encoded temperature = (temp + 40) × 2
Bytes 6-11: 0x00 (reserved)
```

**Example:** 20°C → (20 + 40) × 2 = 120 → 0x78

---

### 5. Fuel Consumption (Command 0x22)

| Field | Value |
| --- | --- |
| **Update Rate** | 1000ms |
| **Payload Length** | 3 bytes |

**Payload Structure:**
```
Byte 0: Unit (0x02 = L/100km)
Byte 1: Value MSB
Byte 2: Value LSB
```

**Formula:** `consumption_L100km = (Byte1 << 8 | Byte2) / 10.0`

**Example:** 7.5 L/100km → 75 → 0x004B → Payload: `02 00 4B`

---

### 5b. Average Fuel Consumption (Command 0x23)

| Field | Value |
| --- | --- |
| **Update Rate** | 5000ms |
| **Payload Length** | 3 bytes |

**Payload Structure:**
```
Byte 0: Unit (0x02 = L/100km)
Byte 1: Value MSB
Byte 2: Value LSB
```

**Formula:** `consumption_L100km = (Byte1 << 8 | Byte2) / 10.0`

**Example:** 8.2 L/100km → 82 → 0x0052 → Payload: `02 00 52`

**Notes:**
- Same format as 0x22 but for trip average consumption
- Data from Nissan CAN 0x580 byte[4]

---

### 6. Trip Info / Remaining Range (Command 0x21)

| Field | Value |
| --- | --- |
| **Update Rate** | 5000ms |
| **Payload Length** | 7 bytes |

**Payload Structure:**
```
Byte 0: Average Speed MSB (0.1 km/h units)
Byte 1: Average Speed LSB
Byte 2: Elapsed Time MSB (seconds)
Byte 3: Elapsed Time LSB
Byte 4: Range MSB (km)
Byte 5: Range LSB
Byte 6: Unit (0x02 = km)
```

**Formulas:**
- `average_speed_kmh = (Byte0 << 8 | Byte1) / 10.0`
- `elapsed_time_sec = (Byte2 << 8 | Byte3)`
- `range_km = (Byte4 << 8) | Byte5`

**Example:** 45.0 km/h avg, 3600s elapsed, 540 km range → Payload: `01 C2 0E 10 02 1C 02`

---

## Timing Diagram

```
Time (ms)  0    200   333   400   500   600   666   800   1000
           │     │     │     │     │     │     │     │     │
Steering   ■─────■─────────────■─────────────────■─────────■
(0x29)     │                   │                 │
           │           │       │     │           │     │
RPM        ■───────────■───────────────■─────────────────■─
(0x7D/0A)              │             │
           │                         │                   │
Speed      ■─────────────────────────■─────────────────────■
(0x7D/03)
           │                   │                   │
Doors      ■───────────────────■───────────────────■───────
(0x24)     (or on change)

■ = Frame transmitted
```

---

## Data Flow

```
┌─────────────┐      ┌──────────────┐      ┌─────────────┐
│  Global     │ Read │  RadioSend   │ UART │  Android    │
│  Variables  │ ───► │  Module      │ ───► │  Head Unit  │
└─────────────┘      └──────────────┘      └─────────────┘
  currentSteer         Formats data         Displays:
  engineRPM            Calculates CRC       - Camera lines
  vehicleSpeed         Sends frames         - RPM gauge
  currentOdo                                - Speedometer
  currentDoors                              - Door status
  tempExt                                   - Temperature
  dteValue                                  - Remaining range
  averageSpeed                              - Average speed
  elapsedTime                               - Trip time
  fuelConsumptionInst                       - Instant consumption
  fuelConsumptionAvg                        - Average consumption
  headlightsOn                              - Lights status
  highBeamOn                                - Indicators
  parkingLightsOn
  indicatorLeft/Right
```

---

## Debug Notes

The protocol does not require a handshake - data is sent proactively. Any incoming data from the head unit is discarded.

---

## References

### Radio Protocol Documentation
- [smartgauges / canbox](https://github.com/smartgauges/canbox)
- [cxsichen / Raise Protocol](https://github.com/cxsichen/helllo-world/tree/master/%E5%8D%8F%E8%AE%AE/%E7%9D%BF%E5%BF%97%E8%AF%9A)

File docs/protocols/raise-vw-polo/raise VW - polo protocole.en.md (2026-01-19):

Volkswagen Platform – CAN BUS Module to DVD Head Unit Communication Protocol 1.4
===============================================================================

This document describes the communication protocol between the DVD head unit system (HOST) and the CAN BUS decoder (SLAVE).  
It covers the **physical layer**, **data link layer** and **application layer**.

---

Physical Layer
--------------

- **Interface**: standard UART
- **Logic level**: 5 V TTL
- **UART mode**: 8N1  
  - 8 data bits  
  - no parity  
  - 1 stop bit
- **Baud rate**: fixed at **38400 bps**

### Conventions

- **HOST**: DVD / NAVI head unit
- **SLAVE**: CAN BUS decoder

---

Data Link Layer
---------------

### Frame Structure

The UART frame is defined as follows:

| Order | Field | Description |
|---|---|---|
| 1 | Head Code | Fixed to `0x2E` |
| 2 | Data Type | See *Data Type Definition* table below  |
| 3 | Length | Length of the data field |
| 4 | Data0 | |
| 5 | Data1 | |
| 6..N  | … | Data2…DataN (payload) |
| N | Checksum  | See below |

**Checksum**:

\[
Checksum = \bigl(DataType + Length + Data0 + \dots + DataN\bigr) \oplus 0xFF
\]

---

ACK / NACK
----------

### Definition

ACK/NACK is a 1‑byte response frame:

| Value  | Meaning |
|---|---|
| `0xFF` | ACK (frame OK) |
| `0xF0` | NACK (Checksum NG / error) |

- The reply frame **consists of only one byte**.

### Timing Rules

1. After the receiver gets a complete frame, it **must reply with ACK or NACK within 10 ms**.  
2. The sender must be able to receive ACK/NACK in the range **0–100 ms** after sending the frame.  
3. If no ACK is received within 100 ms, the frame **must be retransmitted**.  
   - If the same frame has been retransmitted **three times without ACK**, all further transmissions must be stopped and an appropriate error handling procedure should be executed.

---

Application Layer
-----------------

### Data Type Definition

The `DataType` field defines the semantic of the payload.

#### DataType from SLAVE → HOST

| DataType | Name / Description | Notes |
|---|---|---|
| `0x14` | Backlight level information | Sent on power‑on, whenever backlight changes, and on request |
| `0x16` | Vehicle speed | |
| `0x20` | Steering wheel key information | |
| `0x21` | Air‑conditioning information | |
| `0x22` | Rear parking radar information | |
| `0x23` | Front parking radar information | |
| `0x24` | Basic vehicle information | Decoder sends proactively on change; can also be requested by the head unit |
| `0x25` | Parking assistance status | |
| `0x26` | Steering wheel angle | |
| `0x27` | Amplifier status | |
| `0x30` | Version information | Sent on power‑on or when queried |
| `0x41` | Body information | |

#### DataType from HOST → SLAVE

| DataType | Name / Description | Notes |
|---|---|---|
| `0x81` | Start / End | Connection establishment / release |
| `0x90` | Request control information | Request decoder to send specific data types (`0x14, 0x16, 0x21, 0x24, 0x25, 0x26, 0x30, 0x41`) to the head unit |
| `0xA0` | Amplifier control command | Control external amplifier parameters |
| `0xC0` | Source select | Select active audio/video source |
| `0xC1` | ICON / play‑mode indication | Display state/ICON for current source and play mode |
| `0xC2` | Tuner (radio) information | Frequency, band and preset index |
| `0xC3` | Media playback information | Generic playback information (track, folder, time, etc.) according to media type |
| `0xC4` | Volume OSD control | Volume and mute indication |
| `0xC6` | Radar volume control | Rear‑radar sound enable/disable and parking mode |

---

Detailed Data Formats
---------------------

### 1) Backlight Information – `0x14` (SLAVE → HOST)

| Field | Value | Description |
|---|---|---|
| DataType | `0x14`  | Data type |
| Length | `0x01`  | Length = 1 byte |
| Data0 | 0x00–FF | Key backlight brightness |

- `Data0 = 0x00` → darkest  
- `Data0 = 0xFF` → brightest  
- This value reflects the **OEM key backlight brightness**.  
- If used to control screen brightness, note:  
  - When `Data0 = 0x00`, the environment is bright and key backlight is OFF, so the **screen brightness should be relatively high**.  
- This frame is sent:
  - on power‑on,  
  - whenever the value changes,  
  - and on explicit request.

---

### 2) Vehicle Speed – `0x16` (SLAVE → HOST)

| Field | Value  | Description |
|---|---|---|
| DataType | `0x16` | Data type |
| Length | `0x02` | Length = 2 bytes |
| Data0 | LSB | Least significant byte |
| Data1 | MSB | Most significant byte |

Vehicle speed:

\[
Speed\,(km/h) = \frac{(Data1 \times 256 + Data0)}{16}
\]

---

### 3) Steering Wheel Keys – `0x20` (SLAVE → HOST)

| Field | Value  | Description |
|---|---|---|
| DataType | `0x20` | Data type |
| Length | `0x02` | Length = 2 bytes |

#### Data0 – Key Code

| Value | Meaning |
|---|---|
| 0x00  | No key pressed / key released  |
| 0x01  | VOL+ |
| 0x02  | VOL– |
| 0x03  | `>` / MENU UP |
| 0x04  | `<` / MENU DOWN |
| 0x05  | TEL |
| 0x06  | MUTE |
| 0x07  | SRC |
| 0x08  | MIC |

#### Data1 – Key Status

| Value | Meaning |
|---|---|
| 0 | Key released |
| 1 | Key pressed |
| 2 | Continuous press valid  |

---

### 4) Air‑Conditioning Information – `0x21` (SLAVE → HOST)

| Field | Value  | Description |
|---|---|---|
| DataType | `0x21` | Data type |
| Length | `0x05` | Length = 5 bytes |

#### Data0 – A/C Status

- **Bit7**: A/C main ON/OFF  
  - 0: OFF  
  - 1: ON
- **Bit6**: A/C compressor ON/OFF  
  - 0: A/C OFF  
  - 1: A/C ON
- **Bit5**: Air circulation mode  
  - 0: Fresh air (outside)  
  - 1: Recirculation (inside)
- **Bit4**: AUTO (high fan) indicator  
  - 0: OFF  
  - 1: ON
- **Bit3**: AUTO (low fan) indicator  
  - 0: OFF  
  - 1: ON
- **Bit2**: DUAL indicator  
  - 0: OFF  
  - 1: ON
- **Bit1**: MAX FRONT indicator  
  - 0: OFF  
  - 1: ON
- **Bit0**: REAR indicator  
  - 0: OFF  
  - 1: ON

#### Data1 – Blower and Air Direction

- **Bit7**: Upper vents ON/OFF
- **Bit6**: Front (face‑level) vents ON/OFF
- **Bit5**: Lower vents ON/OFF
- **Bit4**: A/C display request  
  - 0: Do not display  
  - 1: Request to display A/C info
- **Bit3..Bit0**: Fan speed level  
  - 0x00–0x07 → level 0–7

#### Data2 – Driver Temperature

- `0x00`: LO
- `0x1F`: HI
- `0x01–0x11`: 18 °C – 26 °C, step 0.5 °C (other values invalid)

#### Data3 – Passenger Temperature

- Same encoding as Data2 (driver side).

#### Data4 – Seat Heating / AQS

- **Bit7**: AQS recirculation
  - 0: non‑AQS recirculation  
  - 1: AQS recirculation
- **Bit6**: reserved
- **Bit5..Bit4**: Left seat heating level  
  - 00: no display  
  - 01–11: level 1–3
- **Bit1..Bit0**: Right seat heating level  
  - 00: no display  
  - 01–11: level 1–3

---

### 5) Rear Parking Radar – `0x22` (SLAVE → HOST)

Sent **only when distances change**.

| Field | Value  | Description |
|---|---|---|
| DataType | `0x22` | Data type |
| Length | `0x04` | Length = 4 bytes |

For all distance bytes below:

- `0x00`: no display  
- `0x01`: nearest  
- `0x0A`: farthest  
- Range: `0x00–0x0A`

| Byte | Description |
|---|---|
| Data0  | Rear left sensor distance |
| Data1  | Rear left‑center sensor distance |
| Data2  | Rear right‑center sensor distance |
| Data3  | Rear right sensor distance |

---

### 6) Front Parking Radar – `0x23` (SLAVE → HOST)

Also sent **only when distances change**.

| Field | Value  | Description |
|---|---|---|
| DataType | `0x23` | Data type |
| Length | `0x04` | Length = 4 bytes |

Distance encoding is the same as for `0x22`.

| Byte | Description |
|---|---|
| Data0  | Front left sensor distance |
| Data1  | Front left‑center sensor distance |
| Data2  | Front right‑center sensor distance |
| Data3  | Front right sensor distance |

---

### 7) Basic Information – `0x24` (SLAVE → HOST)

Sent **proactively when data changes**, or on **explicit query** by the DVD head unit.

| Field | Value  | Description |
|---|---|---|
| DataType | `0x24` | Data type |
| Length | `0x01` | Length = 1 byte |
| Data0 | | Reverse / parking info |

#### Data0 – Reverse / Parking Info

- **Bit7..Bit3**: reserved
- **Bit2**: Light status  
  - 0: OFF  
  - 1: ON
- **Bit1**: P‑gear or handbrake status  
  - 0: not in P / handbrake released  
  - 1: P gear or handbrake applied
- **Bit0**: Reverse gear status  
  - 0: not in reverse  
  - 1: reverse engaged

---

### 8) Parking Assistance Status – `0x25` (SLAVE → HOST)

| Field | Value  | Description |
|---|---|---|
| DataType | `0x25` | Data type |
| Length | `0x02` | Length = 2 bytes |
| Data0 | | Parking assist system status |
| Data1 | | Reserved |

#### Data0 – Bits

- **Bit7..Bit2**: reserved
- **Bit1**: Parking assist system ON/OFF  
  - 0: OFF  
  - 1: ON
- **Bit0**: Radar sound ON/OFF  
  - 0: no radar sound  
  - 1: radar sound active

---

### 9) Steering Wheel Angle – `0x26` (SLAVE → HOST)

| Field | Value  | Description |
|---|---|---|
| DataType | `0x26` | Data type |
| Length | `0x02` | Length = 2 bytes |
| Data0 | ESP1 | Steering angle low byte |
| Data1 | ESP2 | Steering angle high byte |

Interpretation example:

- `ESP = 0` → steering wheel centered  
- `ESP > 0` → turning left  
- `ESP < 0` → turning right

---

### 10) Body Information – `0x41` (SLAVE → HOST)

| Field | Description |
|---|---|
| DataType | `0x41` |
| Length | `N` (variable) |
| Data0 | Command |
| Data1..11  | Data (depends on command) |

#### Command Table

##### Command `0x01` – Doors / safety / trunk / washer

- `N = 2`
- `Data[1]` bits:
  - Bit7: Driver seat belt  
    - 0: normal (belt fastened)  
    - 1: not fastened
  - Bit6: Washer fluid level  
    - 0: normal  
    - 1: low washer fluid
  - Bit5: Handbrake  
    - 0: normal (released)  
    - 1: handbrake applied
  - Bit4: Trunk status  
    - 0: closed  
    - 1: open
  - Bit3: Rear door (if present)  
    - 0: closed  
    - 1: open
  - Bit2: Left rear door  
    - 0: closed  
    - 1: open
  - Bit1: Right front door  
    - 0: closed  
    - 1: open
  - Bit0: Left front door  
    - 0: closed  
    - 1: open

##### Command `0x02` – Engine / speed / battery / outside temp / mileage / fuel

- `N = 13`

| Bytes | Description |
|---|---|
| Data1–Data2  | Engine RPM: `RPM = Data1 * 256 + Data2` |
| Data3–Data4  | Instantaneous speed (km/h): `(Data3 * 256 + Data4) * 0.01` |
| Data5–Data6  | Battery voltage (V): `(Data5 * 256 + Data6) * 0.01` |
| Data7–Data8  | Outside temperature (°C): `(Data7 * 256 + Data8) * 0.1`.<br>Valid range: −50 °C to 77.5 °C (negative values in 2‑byte two’s‑complement) |
| Data9–Data11 | Trip distance (km): `Data9 * 65536 + Data10 * 256 + Data11` |
| Data12 | Remaining fuel (L): `Fuel = Data12` |

##### Command `0x03` – Warning flags

- `N = 2`
- `Data1` bits:
  - Bit7: Low fuel warning  
    - 1: fuel low; 0: normal
  - Bit6: Battery voltage warning  
    - 1: voltage low; 0: normal
  - Bit5..Bit0: reserved

---

### 11) Amplifier Status – `0x27` (SLAVE → HOST)

Sent when amplifier settings change.

| Field | Value  | Description |
|---|---|---|
| DataType | `0x27` | Data type |
| Length | `0x08` | Length = 8 bytes |

| Byte | Name | Range / Meaning |
|---|---|---|
| Data0  | Amplifier type | `0x00`: no amp; `0x01`: non‑CAN amp; `0xFF`: unknown |
| Data1  | Volume | 0–30 (unsigned char) |
| Data2  | BALANCE | −9 – +9 (signed char) |
| Data3  | FADER | −9 – +9 (signed char) |
| Data4  | BASS | −9 – +9 (signed char) |
| Data5  | MIDTONE | −9 – +9 (signed char) |
| Data6  | TREBLE | −9 – +9 (signed char) |
| Data7  | Speed‑dependent volume | 0–7 (unsigned char) |

---

### 12) Start / End – `0x81` (HOST → SLAVE)

| Field | Value  | Description |
|---|---|---|
| DataType | `0x81` | Data type |
| Length | `0x01` | Length = 1 byte |
| Data0 | | Command type |

#### Data0 – Command Type

| Value | Meaning |
|---|---|
| 0x01  | **Start** – when the system powers up, the HOST sends this command to establish a connection. Connection is successful after SLAVE replies with ACK. |
| 0x00  | **End** – when the system powers down, the HOST sends this command to terminate the connection. After ACK is received from SLAVE, the HOST stops communication. |

---

### 13) Request Control Information – `0x90` (HOST → SLAVE)

| Field | Value  | Description |
|---|---|---|
| DataType | `0x90` | Data type |
| Length | `N` | Data length |

| Byte | Description |
|---|---|
| Data0  | Requested content (see below) |
| Data1  | Used only for `0x41` body info |

**Data0 – Request content:**

- `0x14`: Backlight information  
- `0x16`: Vehicle speed  
- `0x21`: A/C information  
- `0x24`: Basic information  
- `0x25`: Parking assist status  
- `0x26`: Steering angle  
- `0x30`: Version information  
- `0x41`: Body information (command value provided in Data1)

---

### 14) Amplifier Control – `0xA0` (HOST → SLAVE)

| Field | Value  | Description |
|---|---|---|
| DataType | `0xA0` | Data type |
| Length | `0x02` | Length = 2 bytes |

| Byte | Description |
|---|---|
| Data0  | Command |
| Data1  | Parameter |

#### Data0 – Command Codes

| Value | Meaning |
|---|---|
| 0x00  | Volume |
| 0x01  | BALANCE |
| 0x02  | FADER |
| 0x03  | BASS |
| 0x04  | MIDTONE |
| 0x05  | TREBLE |
| 0x06  | Speed‑dependent volume |

#### Parameter Table (Data1)

| Index | Command | Parameter range | Default |
|---|---|---|---|
| 0 | Volume | 0–30 (unsigned char) | 28 |
| 1 | BALANCE | −9 – +9 (signed char) | 0 |
| 2 | FADER | −9 – +9 (signed char) | 0 |
| 3 | BASS | −9 – +9 (signed char) | 0 |
| 4 | MIDTONE | −9 – +9 (signed char) | 0 |
| 5 | TREBLE | −9 – +9 (signed char) | 0 |
| 6 | Speed‑dependent volume | 0–7 (unsigned char) | 0 |

> If no explicit control commands are received, the CAN BOX opens the amplifier with these default settings.

---

### 15) Source – `0xC0` (HOST → SLAVE)

| Field | Value  | Description |
|---|---|---|
| DataType | `0xC0` | Data type |
| Length | `0x02` | Length = 2 bytes |

#### Data0 – Source

| Value | Source |
|---|---|
| 0x00  | OFF |
| 0x01  | Tuner |
| 0x02  | Disc (CD, DVD) |
| 0x03  | TV (analog) |
| 0x04  | NAVI |
| 0x05  | Phone |
| 0x06  | iPod |
| 0x07  | AUX |
| 0x08  | USB |
| 0x09  | SD |
| 0x0A  | DVB‑T |
| 0x0B  | Phone A2DP |
| 0x0C  | Other |
| 0x0D  | CDC v1.02 |

#### Data1 – Media Type

| Value | Media Type |
|---|---|
| 0x01  | Tuner |
| 0x10  | Simple audio media |
| 0x11  | Enhanced audio media |
| 0x12  | iPod |
| 0x20  | File‑based video |
| 0x21  | DVD video |
| 0x22  | Other video |
| 0x30  | AUX / other |
| 0x40  | Phone |

---

### 16) ICON – `0xC1` (HOST → SLAVE)

| Field | Value  | Description |
|---|---|---|
| DataType | `0xC1` | Data type |
| Length | `0x01` | Length = 1 byte |

#### Data0 – Source / Play Mode Flags

- **Bit7..Bit3**: reserved  
- **Bit2..Bit1**: Play mode (v1.02)  
  - `0x00`: Normal  
  - `0x01`: Scan (CD/DVD/TUNER)  
  - `0x02`: Mix (CD/DVD only)  
  - `0x03`: Repeat (CD/DVD only)
- **Bit0**: reserved

---

### 17) Tuner (Radio) Information – `0xC2` (HOST → SLAVE)

| Field | Value  | Description |
|---|---|---|
| DataType | `0xC2` | Data type |
| Length | `0x04` | Length = 4 bytes |

| Byte | Description |
|---|---|
| Data0  | Radio band |
| Data1  | Current frequency LSB |
| Data2  | Current frequency MSB |
| Data3  | Preset index |

#### Data0 – Band

| Value | Band  |
|---|---|
| 0x00  | FM |
| 0x01  | FM1 |
| 0x02  | FM2 |
| 0x03  | FM3 |
| 0x10  | AM |
| 0x11  | AM1 |
| 0x12  | AM2 |
| 0x13  | AM3 |

Frequency:

- FM: `Freq(MHz) = X / 100`  
- AM: `Freq(kHz) = X`

Preset:

- `Data3 = 0..6`, where 0 means *not a preset station*.

---

### 18) Media Playback Information – `0xC3` (HOST → SLAVE)

| Field | Value  | Description |
|---|---|---|
| DataType | `0xC3` | Data type |
| Length | `0x06` | Length = 6 bytes |

| Byte | Description |
|---|---|
| Data0  | Info1 |
| Data1  | Info2 |
| Data2  | Info3 |
| Data3  | Info4 |
| Data4  | Info5 |
| Data5  | Info6 |

The interpretation of Info1..Info6 depends on **Media Type**.

#### Media Type–specific Formats

| Media Type | Description | Info1 | Info2 | Info3 | Info4 | Info5 | Info6 |
|---|---|---|---|---|---|---|---|
| `0x01` | Tuner | Unused | Unused | Unused | Unused | Unused | Unused |
| `0x10` | Simple audio media | Disc number (`0x00` = no disc) | Track number (`0x01–0xFF`) | Unused | Unused | Minute | Second |
| `0x11` | Enhanced audio media | Folder number low byte | Folder number high byte | File number low byte | File number high byte | Minute | Second |
| `0x12` | iPod | Current song number (low byte) | Current song number (high byte) | Total song number (low byte) | Total song number (high byte) | Unused | Unused |
| `0x20` | File‑based video | Folder number low byte | Folder number high byte | File number low byte | File number high byte | Unused | Unused |
| `0x21` | DVD video | Current chapter | Total chapter | Unused | Unused | Minute | Second |
| `0x22` | Other video | Unused | Unused | Unused | Unused | Unused | Unused |
| `0x30` | AUX / other | Unused | Unused | Unused | Unused | Unused | Unused |
| `0x40` | Phone | Unused | Unused | Unused | Unused | Unused | Unused |

---

### 19) Volume Display Control – `0xC4` (HOST → SLAVE)

| Field | Value  | Description |
|---|---|---|
| DataType | `0xC4` | Data type |
| Length | `0x01` | Length = 1 byte |

#### Data0 – Volume Display

- **Bit7**: Mute control  
  - 1: mute  
  - 0: not muted
- **Bit6..Bit0**: Volume value, valid range 0–127

---

### 20) Radar Volume Control – `0xC6` (HOST → SLAVE)

| Field | Value  | Description |
|---|---|---|
| DataType | `0xC6` | Data type |
| Length | `0x02` | Length = 2 bytes |

| Byte | Description |
|---|---|
| Data0  | Command |
| Data1  | Parameter |

#### Command Table

| Index | Command | Description | Parameter values |
|---|---|---|---|
| 1 | 0x00 | Reverse radar sound control | 0x00: disable reverse radar sound<br>0x01: enable reverse radar sound |
| 2 | 0x02 | Parking mode | 0x00: Mode 1 (standard)<br>0x01: Mode 2 (parallel parking along roadside)<br>See vehicle user manual for details |

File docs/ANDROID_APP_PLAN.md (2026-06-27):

# Plan de Développement - Application Android CANBox

> **NOTE IMPORTANTE pour Claude:**
> Ce document a été généré le 2026-01-26. Les versions des dépendances (Compose, Room, Retrofit, etc.)
> listées ci-dessous peuvent être obsolètes. **Vérifie les dernières versions stables** avant de commencer
> l'implémentation. Utilise les sites officiels ou `mvnrepository.com` pour les versions à jour.

## Vue d'ensemble

Application Android pour configurer et monitorer l'ESP32 CANBox via USB série.

**Écran cible:** 1280x720 (720p paysage) - Autoradio Android

**Stack technique proposé:**
- Kotlin
- Jetpack Compose (UI moderne)
- Material Design 3
- usb-serial-for-android (communication USB)
- Retrofit/Ktor (GitHub API pour updates)
- Room (stockage local logs)

---

## Architecture des Écrans

```
┌──────────────────────────────────────────────────────────────────────────────┐
│  [Live] [CAN Config] [Calibration] [Update] [Debug]      🔌 Connecté   v1.7.0│
├──────────────────────────────────────────────────────────────────────────────┤
│                                                                              │
│                           Contenu de l'écran actif                           │
│                              (1280 x ~650 px)                                │
│                                                                              │
└──────────────────────────────────────────────────────────────────────────────┘
```

**Layout paysage 720p (1280x720):**
- Navigation horizontale en haut (tabs)
- Status bar: connexion USB + version firmware
- Zone contenu: ~650px de hauteur utilisable

---

## Écran 1: Live Stats (Dashboard)

**But:** Afficher les données véhicule en temps réel

### UI Components (Paysage 1280x720)
```
┌──────────────────────────────────────────────────────────────────────────────┐
│                                                                              │
│   ┌─────────┐  ┌─────────┐  ┌─────────┐  ┌─────────┐  ┌─────────┐  ┌──────┐ │
│   │  2500   │  │   60    │  │  14.2V  │  │  85°C   │  │   30L   │  │ 350  │ │
│   │   RPM   │  │  km/h   │  │ Batterie│  │  Temp   │  │ Essence │  │ DTE  │ │
│   └─────────┘  └─────────┘  └─────────┘  └─────────┘  └─────────┘  └──────┘ │
│                                                                              │
│   Direction: ←━━━━━━━━━━━━━━━━━━━━━━━●━━━━━━━━━━━━━━━━━━━━━━━→   -150°     │
│                                                                              │
│   ┌────────────────────────────────────┐  ┌────────────────────────────────┐│
│   │  Portes                            │  │  Éclairage                     ││
│   │  [■ AV-G] [□ AV-D] [□ AR-G]       │  │  💡 Codes  🔆 Phares  🔵 Veill ││
│   │  [□ AR-D] [□ Coffre]              │  │  ◀️ Cligno G    ▶️ Cligno D     ││
│   └────────────────────────────────────┘  └────────────────────────────────┘│
│                                                                              │
│   Mode: REAL (Nissan Juke F15)                          Frein à main: OFF   │
│                                                                              │
└──────────────────────────────────────────────────────────────────────────────┘
```

### Commandes USB utilisées
- `SYS DATA` - Polling toutes les 200-500ms
- Parse la réponse pour extraire les valeurs

### Data Model
```kotlin
data class VehicleData(
    val rpm: Int,
    val speed: Int,
    val voltage: Float,
    val temperature: Int,
    val fuelLevel: Int,
    val dte: Int,
    val steering: Int,
    val doors: DoorStatus,
    val lights: LightStatus
)
```

---

## Écran 2: CAN Config (Sélection Véhicule)

**But:** Gérer les profils véhicules (JSON configs)

### UI Components (Paysage 1280x720)
```
┌──────────────────────────────────────────────────────────────────────────────┐
│                                                                              │
│   Config active: Nissan Juke F15 ✓                    Mode: REAL            │
│                                                                              │
│   ┌─────────────────────────────────────┐  ┌─────────────────────────────────┐
│   │  ═══ Sur le device ═══              │  │  ═══ Disponibles (GitHub) ═══  │
│   │                                     │  │                                 │
│   │  ┌───────────────────────────────┐  │  │  ┌───────────────────────────┐ │
│   │  │ 📄 NissanJukeF15.json    ✓    │  │  │  │ 📥 NissanQashqai.json     │ │
│   │  │    2048 bytes     [Supprimer] │  │  │  │    [Télécharger]          │ │
│   │  └───────────────────────────────┘  │  │  └───────────────────────────┘ │
│   │                                     │  │                                 │
│   │  ┌───────────────────────────────┐  │  │  ┌───────────────────────────┐ │
│   │  │ 📄 MockDemo.json              │  │  │  │ 📥 NissanLeaf.json        │ │
│   │  │    512 bytes      [Supprimer] │  │  │  │    [Télécharger]          │ │
│   │  └───────────────────────────────┘  │  │  └───────────────────────────┘ │
│   │                                     │  │                                 │
│   │  [+ Importer fichier local]         │  │  [🔄 Rafraîchir]               │
│   │                                     │  │                                 │
│   └─────────────────────────────────────┘  └─────────────────────────────────┘
│                                                                              │
└──────────────────────────────────────────────────────────────────────────────┘
```

**Note:** Clic sur une config du device = la charge automatiquement

### Commandes USB utilisées
- `CAN STATUS` - Config active et mode (REAL/MOCK)
- `CAN LIST` - Liste des fichiers sur device
- `CAN LOAD <file>` - Charger une config
- `CAN DELETE <file>` - Supprimer une config
- `CAN UPLOAD START/DATA/END` - Upload nouvelle config
- `CAN GET` - Télécharger config actuelle (backup)

### Fonctionnalités
- [ ] Liste des configs sur le device
- [ ] Charger/activer une config
- [ ] Supprimer une config
- [ ] Upload depuis fichier local
- [ ] Download depuis GitHub (repo configs communautaires)
- [ ] Backup config actuelle vers fichier

---

## Écran 3: Calibration

**But:** Ajuster les paramètres de calibration (NVS)

### UI Components (Paysage 1280x720)
```
┌──────────────────────────────────────────────────────────────────────────────┐
│                                                                              │
│   ┌─────────────────────────────────────┐  ┌─────────────────────────────────┐
│   │  ═══ Direction ═══                  │  │  ═══ Moteur & Carburant ═══    │
│   │                                     │  │                                 │
│   │  Steering Offset         [  100  ]  │  │  RPM Divisor          [   7  ] │
│   │  ←━━━━━━━━━━━●━━━━━━━━━━━→         │  │  ←━━━●━━━━━━━━━━━━━━━━━→        │
│   │  -500                      +500     │  │  1                         20   │
│   │                                     │  │                                 │
│   │  Steering Scale (x0.0001)[  300  ]  │  │  Tank Capacity (L)    [  45  ] │
│   │  ←━━●━━━━━━━━━━━━━━━━━━━━→         │  │  ←━━━━━━━━━━━●━━━━━━━━━→        │
│   │  1                        20000     │  │  20                       100   │
│   │                                     │  │                                 │
│   │  Steering Invert    [ OFF | ON ✓]   │  │  DTE Divisor (x100)   [ 283  ] │
│   │                                     │  │  ←━━━━━━━━●━━━━━━━━━━━━→        │
│   │  Indicator Timeout (ms)  [  500  ]  │  │  100                       500  │
│   │  ←━━━━━━━━●━━━━━━━━━━━━━━→         │  │                                 │
│   │  100                       2000     │  │                                 │
│   │                                     │  │                                 │
│   └─────────────────────────────────────┘  └─────────────────────────────────┘
│                                                                              │
│                        [💾 Enregistrer]    [🔄 Réinitialiser]                │
│                                                                              │
└──────────────────────────────────────────────────────────────────────────────┘
```

### Commandes USB utilisées
- `CFG LIST` - Charger toutes les valeurs actuelles
- `CFG SET <param> <value>` - Modifier une valeur
- `CFG SAVE` - Sauvegarder en NVS
- `CFG RESET` - Reset aux valeurs par défaut

### Fonctionnalités
- [ ] Charger valeurs actuelles au démarrage
- [ ] Sliders avec preview en temps réel
- [ ] Validation des ranges
- [ ] Bouton "Test" (applique sans sauvegarder)
- [ ] Bouton "Sauvegarder" (CFG SAVE)
- [ ] Bouton "Reset" avec confirmation

---

## Écran 4: Update (Firmware)

**But:** Mettre à jour le firmware ESP32

### UI Components (Paysage 1280x720)
```
┌──────────────────────────────────────────────────────────────────────────────┐
│                                                                              │
│   Version actuelle: 1.7.0 (2026-01-26)                                       │
│                                                                              │
│   ┌─────────────────────────────────────┐  ┌─────────────────────────────────┐
│   │  ═══ GitHub Releases ═══            │  │  ═══ Détails / Installation ═══│
│   │                                     │  │                                 │
│   │  ┌───────────────────────────────┐  │  │  v1.8.0 (Latest)               │
│   │  │ ⬇️ v1.8.0 (Latest)       NEW  │  │  │                                 │
│   │  └───────────────────────────────┘  │  │  Changelog:                     │
│   │  ┌───────────────────────────────┐  │  │  - Fix temperature display     │
│   │  │ ✓ v1.7.0 (Installée)          │  │  │  - Add new CAN frames          │
│   │  └───────────────────────────────┘  │  │  - Improve steering accuracy   │
│   │  ┌───────────────────────────────┐  │  │                                 │
│   │  │   v1.6.0                      │  │  │  Taille: 413 KB                │
│   │  └───────────────────────────────┘  │  │  Date: 2026-01-28              │
│   │                                     │  │                                 │
│   │  [🔄 Rafraîchir]                    │  │  [⬇️ Télécharger & Installer]   │
│   │                                     │  │                                 │
│   └─────────────────────────────────────┘  └─────────────────────────────────┘
│                                                                              │
│   [📁 Installer depuis fichier local]                                        │
│                                                                              │
├──────────────────────────────────────────────────────────────────────────────┤
│   Installation: ████████████████░░░░░░░░░░░░░░  45%    185 / 413 KB          │
│   Méthode: esptool (rapide)                                       [Annuler]  │
└──────────────────────────────────────────────────────────────────────────────┘
```

### GitHub API Integration
```kotlin
// Fetch releases from GitHub
interface GitHubApi {
    @GET("repos/{owner}/{repo}/releases")
    suspend fun getReleases(
        @Path("owner") owner: String,
        @Path("repo") repo: String
    ): List<Release>
}

data class Release(
    val tag_name: String,      // "v1.8.0"
    val name: String,          // "Version 1.8.0"
    val body: String,          // Release notes (markdown)
    val published_at: String,
    val assets: List<Asset>
)

data class Asset(
    val name: String,          // "firmware.bin"
    val browser_download_url: String,
    val size: Int
)
```

### Commandes USB utilisées
- `SYS INFO` - Version actuelle
- `SYS BOOTLOADER` - Mode esptool (recommandé)
- `OTA START/DATA/END` - Fallback base64

### Workflow Update
```
1. User sélectionne version
       ↓
2. Télécharge .bin depuis GitHub (ou local)
       ↓
3. Calcule MD5 du fichier
       ↓
4. Essaie méthode esptool:
   a. Envoie "SYS BOOTLOADER"
   b. Attend reconnexion USB
   c. Flash via protocole esptool
       ↓
   Si échec esptool → Fallback OTA (protocole v2):
   a. Pre-flight: "OTA ABORT" + drain 1s
   b. "OTA START <size> <md5>"
   c. Pour chaque chunk (180 bytes):
      - Calcule CRC32 du chunk binaire
      - Envoie "OTA DATA <base64> <crc32>"
      - Attend OK: si CRC mismatch → retry chunk (3x max)
      - Si timeout → OTA ABORT + restart complet
   d. "OTA END"
       ↓
5. Device redémarre
       ↓
6. Vérifie nouvelle version avec "SYS INFO"
```

> **Implémentation OTA:** voir `docs/protocols/OTA_PROTOCOL.md` pour le protocole v2 complet
> et l'exemple Kotlin (`OtaUpdater` class) à utiliser dans `UpdateViewModel.kt`.

### Fonctionnalités
- [ ] Fetch releases depuis GitHub API
- [ ] Afficher release notes
- [ ] Télécharger firmware
- [ ] Flash via esptool (rapide)
- [ ] Fallback OTA serial (lent mais fiable)
- [ ] Progress bar
- [ ] Sélection fichier local
- [ ] Vérification MD5

---

## Écran 5: Debug (Logs CAN)

**But:** Visualiser et enregistrer les trames CAN

### UI Components (Paysage 1280x720)
```
┌──────────────────────────────────────────────────────────────────────────────┐
│                                                                              │
│   [▶ Start] [⏸ Pause] [🗑 Clear]    💾 Log: OFF     Stats: 1,234 | 45/sec   │
│                                                                              │
│   ┌────────────────────────────────────────────────────┐  ┌─────────────────┐│
│   │  Timestamp     ID      DLC   Data                  │  │  Filtres        ││
│   │  ─────────────────────────────────────────────────│  │                 ││
│   │  12:34:56.123  0x002   [8]  00 0B 60 00 00 00 00  │  │  [x] 0x002 Dir  ││
│   │  12:34:56.156  0x180   [8]  45 E0 00 00 00 00 00  │  │  [x] 0x180 RPM  ││
│   │  12:34:56.189  0x284   [8]  00 3C 00 00 00 00 00  │  │  [x] 0x284 Spd  ││
│   │  12:34:56.223  0x5C5   [8]  1E 00 C3 50 00 00 00  │  │  [x] 0x5C5 Fuel ││
│   │  12:34:56.256  0x002   [8]  00 0B 61 00 00 00 00  │  │  [ ] 0x60D Door ││
│   │  12:34:56.289  0x6F6   [8]  8E 00 00 00 00 00 00  │  │  [x] 0x6F6 Volt ││
│   │  12:34:56.323  0x180   [8]  45 E1 00 00 00 00 00  │  │                 ││
│   │  12:34:56.356  0x551   [8]  7D 00 00 00 00 00 00  │  │  [+ Ajouter ID] ││
│   │  ...                                              │  │                 ││
│   │                                                   │  │  ───────────────││
│   │                                                   │  │  Décodage:      ││
│   │                                                   │  │  [ ] Afficher   ││
│   │                                                   │  │      valeurs    ││
│   └────────────────────────────────────────────────────┘  └─────────────────┘│
│                                                                              │
└──────────────────────────────────────────────────────────────────────────────┘
```

**Note:** Tab "CAN Poste" (Toyota RAV4 TX) sera ajouté plus tard côté ESP32

### Commandes USB utilisées
- `LOG ON` - Active le logging CAN
- `LOG OFF` - Désactive le logging
- Parse les lignes `RX 0xXXX [N]: XX XX XX...`

### Data Model
```kotlin
data class CanFrame(
    val timestamp: Long,
    val direction: Direction,  // RX or TX
    val canId: Int,
    val data: ByteArray,
    val source: Source  // VEHICLE or HEADUNIT
)

enum class Direction { RX, TX }
enum class Source { VEHICLE, HEADUNIT }
```

### Fonctionnalités
- [ ] Affichage temps réel des trames
- [ ] Filtrage par CAN ID
- [ ] Pause/Resume
- [ ] Clear buffer
- [ ] Export vers fichier (CSV ou raw)
- [ ] Fichiers séparés: `vehicle_can_YYYYMMDD_HHMMSS.log`
- [ ] Stats: frames/sec, total frames
- [ ] Décodage intelligent (afficher "Steering: -150" au lieu de raw bytes)

### Logging vers fichier
```kotlin
// Fichier vehicle CAN
/storage/emulated/0/CANBox/logs/vehicle_can_20260126_143052.log

// Format:
// timestamp,direction,can_id,dlc,data
1706277052123,RX,0x002,8,00 0B 60 00 00 00 00 00
1706277052156,RX,0x180,8,45 E0 00 00 00 00 00 00
```

---

## Services & Architecture

### USB Serial Service
```kotlin
class UsbSerialService : Service() {
    private var connection: UsbSerialPort?

    fun connect(): Boolean
    fun disconnect()
    fun sendCommand(cmd: String): String
    fun startStreaming(callback: (String) -> Unit)
    fun stopStreaming()
}
```

### Repository Pattern
```kotlin
interface CanBoxRepository {
    // Live data
    suspend fun getVehicleData(): VehicleData
    fun observeVehicleData(): Flow<VehicleData>

    // Config
    suspend fun getCalibration(): CalibrationConfig
    suspend fun setCalibration(param: String, value: Int)
    suspend fun saveCalibration()

    // CAN configs
    suspend fun listCanConfigs(): List<CanConfigFile>
    suspend fun loadCanConfig(filename: String)
    suspend fun uploadCanConfig(filename: String, content: ByteArray)

    // Firmware
    suspend fun getFirmwareInfo(): FirmwareInfo
    suspend fun flashFirmware(firmware: ByteArray, onProgress: (Int) -> Unit)

    // Debug
    fun observeCanFrames(): Flow<CanFrame>
    suspend fun setCanLogging(enabled: Boolean)
}
```

---

## Structure du Projet

```
app/
├── src/main/java/com/example/canbox/
│   ├── MainActivity.kt
│   ├── ui/
│   │   ├── theme/
│   │   ├── navigation/
│   │   │   └── BottomNavigation.kt
│   │   ├── screens/
│   │   │   ├── live/
│   │   │   │   ├── LiveScreen.kt
│   │   │   │   └── LiveViewModel.kt
│   │   │   ├── canconfig/
│   │   │   │   ├── CanConfigScreen.kt
│   │   │   │   └── CanConfigViewModel.kt
│   │   │   ├── calibration/
│   │   │   │   ├── CalibrationScreen.kt
│   │   │   │   └── CalibrationViewModel.kt
│   │   │   ├── update/
│   │   │   │   ├── UpdateScreen.kt
│   │   │   │   └── UpdateViewModel.kt
│   │   │   └── debug/
│   │   │       ├── DebugScreen.kt
│   │   │       └── DebugViewModel.kt
│   │   └── components/
│   │       ├── GaugeWidget.kt
│   │       ├── SteeringIndicator.kt
│   │       ├── DoorStatusView.kt
│   │       └── CanFrameRow.kt
│   ├── data/
│   │   ├── repository/
│   │   │   └── CanBoxRepository.kt
│   │   ├── usb/
│   │   │   ├── UsbSerialService.kt
│   │   │   └── CommandParser.kt
│   │   ├── github/
│   │   │   └── GitHubApi.kt
│   │   └── local/
│   │       └── LogDatabase.kt
│   ├── domain/
│   │   └── model/
│   │       ├── VehicleData.kt
│   │       ├── CalibrationConfig.kt
│   │       ├── CanFrame.kt
│   │       └── FirmwareInfo.kt
│   └── di/
│       └── AppModule.kt (Hilt/Koin)
├── src/main/res/
└── build.gradle.kts
```

---

## Dépendances

```kotlin
// build.gradle.kts
dependencies {
    // Core
    implementation("androidx.core:core-ktx:1.12.0")
    implementation("androidx.lifecycle:lifecycle-runtime-ktx:2.7.0")

    // Compose
    implementation(platform("androidx.compose:compose-bom:2024.01.00"))
    implementation("androidx.compose.ui:ui")
    implementation("androidx.compose.material3:material3")
    implementation("androidx.navigation:navigation-compose:2.7.6")

    // USB Serial
    implementation("com.github.mik3y:usb-serial-for-android:3.7.0")

    // Networking (GitHub API)
    implementation("com.squareup.retrofit2:retrofit:2.9.0")
    implementation("com.squareup.retrofit2:converter-gson:2.9.0")
    implementation("com.squareup.okhttp3:okhttp:4.12.0")

    // Local DB (logs)
    implementation("androidx.room:room-runtime:2.6.1")
    implementation("androidx.room:room-ktx:2.6.1")
    kapt("androidx.room:room-compiler:2.6.1")

    // DI
    implementation("io.insert-koin:koin-android:3.5.0")
    implementation("io.insert-koin:koin-androidx-compose:3.5.0")

    // Coroutines
    implementation("org.jetbrains.kotlinx:kotlinx-coroutines-android:1.7.3")
}
```

---

## Ordre d'Implémentation

### Phase 1: Setup & Connexion USB
- [ ] Créer projet Android Studio
- [ ] Setup Jetpack Compose + Navigation
- [ ] Intégrer usb-serial-for-android
- [ ] Tester connexion basique (envoyer HELP, recevoir réponse)
- [ ] Service USB avec reconnexion automatique

### Phase 2: Écran Live Stats
- [ ] UI avec gauges
- [ ] Parsing SYS DATA
- [ ] Polling automatique
- [ ] Affichage temps réel

### Phase 3: Écran Calibration
- [ ] UI avec sliders
- [ ] CFG GET/SET/SAVE
- [ ] Validation ranges

### Phase 4: Écran CAN Config
- [ ] Liste fichiers (CAN LIST)
- [ ] Charger config (CAN LOAD)
- [ ] Upload config (CAN UPLOAD)
- [ ] Import fichier local

### Phase 5: Écran Update
- [ ] GitHub API integration
- [ ] Téléchargement firmware
- [ ] SYS BOOTLOADER + esptool
- [ ] Fallback OTA serial
- [ ] Progress UI

### Phase 6: Écran Debug
- [ ] LOG ON/OFF
- [ ] Parsing frames CAN
- [ ] Filtres
- [ ] Export fichier

### Phase 7: Polish
- [ ] Gestion erreurs
- [ ] Tests
- [ ] UI polish
- [ ] Release APK

---

## Décisions Techniques

| Sujet | Décision |
|---|---|
| **Logs CAN poste (TX)** | Pas prioritaire, à implémenter plus tard côté ESP32 |
| **esptool Android** | Utiliser une lib existante (ex: esptool-android) |
| **Sources firmware** | Local (fichier .bin) OU distant (GitHub releases) |
| **Sources CAN config** | Local (fichier .json) OU distant (GitHub) |

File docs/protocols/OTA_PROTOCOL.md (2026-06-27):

# OTA Firmware Update Protocol — v2

Documentation du protocole de mise à jour firmware via USB série pour l'application Android.

> **Application requise** : [ESP32 CANBox Manager](https://github.com/aerodomigue/esp32-canbox-manager)

## Changements par rapport à v1

| Item | v1 | v2 |
|---|----|----|
| Réponse `OTA START` | `OK READY` en premier, puis lignes info | Lignes info d'abord, `OK READY` en **dernier** |
| Écho série | Chaque caractère reçu est renvoyé | **Aucun écho** pendant l'OTA |
| Vérification par chunk | Aucune (seulement MD5 global à la fin) | CRC32 optionnel par chunk (retry safe) |
| Timeout auto-abort | Aucun | **60 secondes** sans `OTA DATA` → abort automatique |
| Pre-flight Android | Aucun | Envoyer `OTA ABORT` avant `OTA START` |
| Retry chunk | Non supporté | CRC mismatch → retry possible (timeout → restart complet) |

---

## Paramètres de connexion

| Paramètre | Valeur |
|---|---|
| Baud rate | 115200 (ignoré par USB CDC) |
| Data bits | 8 |
| Parity | None |
| Stop bits | 1 |
| Flow control | None |
| Line ending envoyé | `\n` (LF) |
| Line ending reçu | `\n` ou `\r\n` (trim avant parsing) |

---

## Protocole

### Pre-flight (nouveau v2)

Avant chaque session OTA, envoyer `OTA ABORT` pour effacer tout état bloqué.

```
OTA ABORT\n
```

Réponse (ignorée — peut arriver ou non selon l'état actuel) :
```
OTA aborted
```

Après envoi, attendre 1 seconde en drainant le buffer RX avant de continuer.

---

### Étape 1 : Démarrer la mise à jour

**Requête :**
```
OTA START <size> [md5]\n
```

| Paramètre | Type | Description |
|---|---|---|
| `size` | integer | Taille du firmware en bytes |
| `md5` | string (optionnel) | Hash MD5 du firmware (32 hex chars) |

**Réponse (succès) v2 — info lines AVANT OK READY :**
```
OTA starting: expecting <size> bytes\n
MD5: <md5>\n                           ← absent si aucun MD5 fourni
OK READY\n                             ← ligne terminale à détecter
```

**Important :** `OK READY` est la **dernière** ligne de la réponse. Le client Android doit lire jusqu'à trouver une ligne commençant par `OK` ou `ERROR` — les lignes précédentes sont informatives.

**Réponse (erreur) :**
```
ERROR: <message>\n
```

Erreurs possibles :
- `OTA already in progress` — envoyer `OTA ABORT` d'abord
- `Invalid firmware size`
- `Firmware too large`
- `Update.begin failed`

---

### Étape 2 : Envoyer les données

Envoyer le firmware en chunks encodés en base64.

**Requête :**
```
OTA DATA <base64_chunk> [crc32_hex]\n
```

| Paramètre | Type | Description |
|---|---|---|
| `base64_chunk` | string | Chunk firmware en base64 (max 240 chars) |
| `crc32_hex` | string (optionnel) | CRC32 du chunk binaire, format hex 8 chars |

**Taille de chunk recommandée :** 180 bytes binaires = 240 chars base64

> La commande totale (`OTA DATA ` + 240 base64 + ` ` + 8 CRC32 + `\n`) = 259 chars, dans la limite des 320 bytes du buffer.

**Écho désactivé :** l'ESP32 n'écho plus les caractères reçus pendant l'OTA. La seule réponse est la ligne `OK` ou `ERROR`.

**Réponse (succès) :**
```
OK <received>/<total> (<percent>%)\n
```
Exemple : `OK 180/451488 (0%)`

**Réponse (erreur CRC — chunk non écrit, retry possible) :**
```
ERROR: CRC mismatch chunk (got <actual_hex> expected <expected_hex>)\n
```

**Comportement sur CRC mismatch :**
- Le chunk n'est **pas écrit** en flash
- `otaReceivedSize` est **inchangé**
- L'OTA reste active
- Le client Android peut **retransmettre le même chunk** immédiatement (sûr)

**Autres erreurs (OTA abortée) :**
```
ERROR: <message>\n
```
Si une erreur autre que CRC mismatch survient, l'OTA est abortée automatiquement. Envoyer `OTA ABORT` puis recommencer depuis le début.

---

### Étape 3 : Finaliser la mise à jour

**Requête :**
```
OTA END\n
```

**Réponse (succès) :**
```
MD5 verified OK\n
OK\n
Firmware updated successfully!\n
Rebooting in 2 seconds...\n
```

Le client doit détecter la ligne `OK` (pas la ligne `MD5 verified OK`). L'ESP32 redémarre automatiquement 2 secondes après.

**Réponse (erreur) :**
```
ERROR: <message>\n
```

---

### Commandes auxiliaires

#### Annuler une mise à jour
```
OTA ABORT\n
```
Réponse : `OTA aborted` (pas de préfixe OK/ERROR — à ignorer ou drainer)

#### Vérifier le statut
```
OTA STATUS\n
```
Réponse :
```
=== OTA Status ===
Update in progress: YES/NO
Progress: <received> / <total> bytes (<percent>%)
Expected MD5: <md5>
Free sketch space: <bytes> bytes
Current firmware size: <bytes> bytes
==================
```

---

## Timeout auto-abort (nouveau v2)

Si aucune commande `OTA DATA` n'est reçue pendant **60 secondes** après `OTA START` ou le dernier `OTA DATA`, l'ESP32 abandonne automatiquement l'OTA :

```
OTA timeout: no data for 60s, aborting\n
OTA aborted\n
```

Le client Android doit relancer une session complète depuis le pre-flight.

---

## Diagramme de séquence v2

```
┌─────────┐                                        ┌─────────┐
│ Android │                                        │  ESP32  │
└────┬────┘                                        └────┬────┘
     │                                                  │
     │  OTA ABORT\n              (pre-flight)           │
     │─────────────────────────────────────────────────>│
     │  OTA aborted  (ou silence si idle)               │
     │<─────────────────────────────────────────────────│
     │ [drain 1s]                                       │
     │                                                  │
     │  OTA START 451488 abc123...def456\n              │
     │─────────────────────────────────────────────────>│
     │                                                  │ Update.begin()
     │  OTA starting: expecting 451488 bytes\n          │ Flush RX buffer
     │<─────────────────────────────────────────────────│
     │  MD5: abc123...def456\n                          │
     │<─────────────────────────────────────────────────│
     │  OK READY\n                ← ligne terminale     │
     │<─────────────────────────────────────────────────│
     │                                                  │
     │  OTA DATA <240b64> <8crc32>\n  (aucun écho)     │
     │─────────────────────────────────────────────────>│
     │                                                  │ CRC32 check
     │                                                  │ WDT reset
     │                                                  │ Update.write() [20-100ms]
     │                                                  │ WDT reset
     │  OK 180/451488 (0%)\n                            │
     │<─────────────────────────────────────────────────│
     │                                                  │
     │  OTA DATA <240b64> <8crc32>\n  (CRC invalide)   │
     │─────────────────────────────────────────────────>│
     │  ERROR: CRC mismatch chunk ...\n ← rien écrit   │
     │<─────────────────────────────────────────────────│
     │  [retry même chunk]                              │
     │  OTA DATA <240b64> <8crc32>\n  (CRC correct)    │
     │─────────────────────────────────────────────────>│
     │  OK 360/451488 (0%)\n                            │
     │<─────────────────────────────────────────────────│
     │                                                  │
     │           ... (répéter ~2508 chunks) ...         │
     │                                                  │
     │  OTA DATA <240b64> <8crc32>\n                   │
     │─────────────────────────────────────────────────>│
     │  OK 451488/451488 (100%)\n                       │
     │<─────────────────────────────────────────────────│
     │                                                  │
     │  OTA END\n                                       │
     │─────────────────────────────────────────────────>│
     │                                                  │ MD5 final
     │                                                  │ Update.end()
     │                                                  │ esp_ota_mark_valid
     │  MD5 verified OK\n                               │
     │<─────────────────────────────────────────────────│
     │  OK\n                    ← ligne terminale       │
     │<─────────────────────────────────────────────────│
     │                                                  │ delay(2s) → restart
     │  [USB déconnecte ~2s plus tard]                  │
```

---

## Implémentation Kotlin (v2)

```kotlin
import android.util.Base64
import java.io.IOException
import java.security.MessageDigest
import java.util.zip.CRC32

class OtaUpdater(private val serialPort: UsbSerialPort) {

    companion object {
        const val CHUNK_SIZE = 180          // bytes binaires par chunk
        const val START_TIMEOUT_MS = 3000L
        const val CHUNK_TIMEOUT_MS = 5000L
        const val ABORT_DRAIN_MS = 1000L
        const val READ_POLL_MS = 50L
        const val MAX_CRC_RETRIES = 3
        const val CRC_RETRY_PAUSE_MS = 200L
    }

    suspend fun updateFirmware(
        firmware: ByteArray,
        onProgress: (sent: Int, total: Int) -> Unit
    ): Result<Unit> = withContext(Dispatchers.IO) {

        val md5 = firmware.md5Hex()

        // 1. Pre-flight : effacer tout état bloqué
        sendRaw("OTA ABORT\n")
        drainUntilQuiet(ABORT_DRAIN_MS)

        // 2. Démarrer
        sendRaw("OTA START ${firmware.size} $md5\n")
        val startResp = readResponse(START_TIMEOUT_MS)
            ?: return@withContext Result.failure(OtaException("OTA START timeout"))
        if (!startResp.startsWith("OK")) {
            return@withContext Result.failure(OtaException("OTA START failed: $startResp"))
        }

        // 3. Envoi des chunks avec retry sur CRC mismatch
        var sent = 0
        var chunkIdx = 0
        val total = firmware.size

        while (sent < total) {
            val chunk = firmware.copyOfRange(sent, minOf(sent + CHUNK_SIZE, total))
            val b64 = Base64.encodeToString(chunk, Base64.NO_WRAP)
            val crc = chunk.crc32Hex()
            val command = "OTA DATA $b64 $crc\n"

            var chunkAccepted = false

            for (attempt in 1..MAX_CRC_RETRIES) {
                sendRaw(command)
                val resp = readResponse(CHUNK_TIMEOUT_MS)

                when {
                    resp == null -> {
                        // Timeout : le flash a PEUT-ÊTRE été écrit → restart complet
                        sendRaw("OTA ABORT\n")
                        return@withContext Result.failure(
                            OtaException("Chunk $chunkIdx timeout — restart OTA from scratch")
                        )
                    }
                    resp.startsWith("OK") -> {
                        chunkAccepted = true
                        break
                    }
                    resp.contains("CRC mismatch", ignoreCase = true) -> {
                        // Rien n'a été écrit → retry du même chunk est sûr
                        if (attempt == MAX_CRC_RETRIES) {
                            sendRaw("OTA ABORT\n")
                            return@withContext Result.failure(
                                OtaException("Chunk $chunkIdx CRC failed $MAX_CRC_RETRIES times")
                            )
                        }
                        delay(CRC_RETRY_PAUSE_MS)
                    }
                    resp.startsWith("ERROR") -> {
                        sendRaw("OTA ABORT\n")
                        return@withContext Result.failure(
                            OtaException("Chunk $chunkIdx rejected: $resp")
                        )
                    }
                }
            }

            if (!chunkAccepted) {
                sendRaw("OTA ABORT\n")
                return@withContext Result.failure(OtaException("Chunk $chunkIdx failed"))
            }

            sent += chunk.size
            chunkIdx++
            onProgress(sent, total)
        }

        // 4. Finaliser
        sendRaw("OTA END\n")
        val endResp = readResponse(CHUNK_TIMEOUT_MS)
        if (endResp == null || !endResp.startsWith("OK")) {
            return@withContext Result.failure(
                OtaException("OTA END failed: ${endResp ?: "timeout"}")
            )
        }

        Result.success(Unit)
        // L'ESP32 redémarre dans ~2s, l'USB se déconnecte
    }

    /**
     * Lit depuis le port série jusqu'à trouver une ligne commençant par OK ou ERROR.
     * Toutes les lignes précédentes (info lines) sont ignorées.
     * Retourne null en cas de timeout.
     */
    private fun readResponse(timeoutMs: Long): String? {
        val buffer = ByteArray(512)
        val accumulator = StringBuilder()
        val deadline = System.currentTimeMillis() + timeoutMs

        while (System.currentTimeMillis() < deadline) {
            val len = try {
                serialPort.read(buffer, READ_POLL_MS.toInt())
            } catch (e: IOException) {
                return null
            }

            if (len > 0) {
                accumulator.append(String(buffer, 0, len, Charsets.UTF_8))
            }

            // Chercher la ligne terminale dans toutes les lignes accumulées
            for (line in accumulator.toString().split('\n')) {
                val trimmed = line.trim()
                if (trimmed.startsWith("OK") || trimmed.startsWith("ERROR")) {
                    return trimmed
                }
            }
        }

        return null
    }

    private suspend fun drainUntilQuiet(timeoutMs: Long) {
        val buf = ByteArray(256)
        val deadline = System.currentTimeMillis() + timeoutMs
        while (System.currentTimeMillis() < deadline) {
            try { serialPort.read(buf, 100) } catch (_: IOException) { break }
            delay(10)
        }
    }

    private fun sendRaw(cmd: String) {
        serialPort.write(cmd.toByteArray(Charsets.UTF_8), 1000)
    }

    private fun ByteArray.md5Hex(): String {
        val md = MessageDigest.getInstance("MD5")
        return md.digest(this).joinToString("") { "%02x".format(it) }
    }

    private fun ByteArray.crc32Hex(): String {
        val crc = CRC32().also { it.update(this) }
        return "%08x".format(crc.value)
    }
}

class OtaException(message: String) : Exception(message)
```

---

## Gestion des erreurs

| Situation | Retry chunk ? | Action |
|---|:---:|---|
| START timeout | Non | Afficher erreur, proposer retry complet |
| START ERROR | Non | Afficher message d'erreur |
| Chunk CRC mismatch | **Oui (3x max)** | Retransmettre le même chunk — sûr (rien écrit) |
| Chunk timeout | Non | `OTA ABORT` → restart complet |
| Chunk ERROR (autre) | Non | `OTA ABORT` → restart complet |
| END timeout/ERROR | Non | Attendre 5s, reconnecter, vérifier `SYS INFO` |
| IOException USB | Non | Reconnecter → `OTA ABORT` → restart |
| Auto-abort 60s | Non | L'ESP32 a déjà aborté → restart depuis pre-flight |

---
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

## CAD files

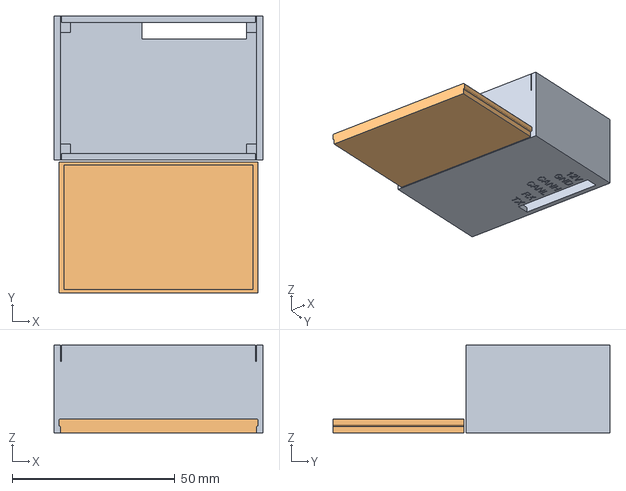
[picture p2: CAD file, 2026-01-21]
hardware/3d-prints/canbox-enclosure.3mf
64.3 x 85.1 x 27.0 mm

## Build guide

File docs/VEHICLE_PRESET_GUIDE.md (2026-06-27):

# Vehicle Preset Guide

How to create a CAN configuration for your vehicle.

---

## Overview

A vehicle preset is a JSON file that tells the ESP32 how to decode CAN frames from your car. Each vehicle has different CAN IDs and data formats, so you need a preset specific to your model.

---

## File Structure

```json
{
  "name": "Make Model Year",
  "isMock": false,
  "vehicleParams": {
    "steerScale": 300,
    "steerOffset": 100,
    "steerInvert": true,
    "indTimeout": null,
    "rpmDiv": null,
    "tankCap": null,
    "dteDiv": null
  },
  "frames": [
    {
      "canId": "0x180",
      "fields": [
        {
          "target": "ENGINE_RPM",
          "startByte": 0,
          "byteCount": 2,
          "byteOrder": "BE",
          "dataType": "UINT16",
          "formula": "SCALE",
          "params": [1, 7, 0]
        }
      ]
    }
  ]
}
```

---

## Fields Reference

### Root Object

| Field | Type | Description |
|---|---|---|
| `name` | string | Vehicle name (displayed in logs) |
| `isMock` | boolean | `true` = simulate data, `false` = read real CAN |
| `vehicleParams` | object (optional) | Calibration overrides for this model — see [Vehicle Parameters](#vehicle-parameters-vehicleparams) |
| `frames` | array | List of CAN frames to decode |

### Frame Object

| Field | Type | Description |
|---|---|---|
| `canId` | string | CAN identifier in hex (e.g., `"0x180"`) |
| `fields` | array | Data fields to extract from this frame |

### Field Object

| Field | Type | Description |
|---|---|---|
| `target` | string | Output variable (see [Targets](#targets)) |
| `startByte` | int | Starting byte index (0-7) |
| `byteCount` | int | Number of bytes to read (1-4) |
| `byteOrder` | string | `"BE"` (Big Endian) or `"LE"` (Little Endian) |
| `dataType` | string | How to interpret bytes (see [Data Types](#data-types)) |
| `formula` | string | Conversion formula (see [Formulas](#formulas)) |
| `params` | array | Formula parameters |

---

## Vehicle Parameters (`vehicleParams`)

The optional `vehicleParams` object embeds vehicle-specific calibration directly in the preset file. When a new vehicle is loaded, these values are applied automatically and saved to persistent storage (NVS).

### Null semantics

Each field is independently nullable:

| Value | Behaviour |
|---|---|
| Concrete value (`300`, `true`, …) | Overrides the in-memory config and is saved to NVS |
| `null` or key absent | No change — current NVS value or firmware default is kept |

### Priority

```
NVS (same vehicle loaded again)  ← highest priority
  vehicleParams (vehicle switch)
    firmware defaults             ← lowest priority
```

When the **same vehicle file** is loaded again (e.g., on reboot), NVS values are preserved and `vehicleParams` is **not** re-applied. This ensures user calibrations made via `CFG SET` survive reboots.

When a **different vehicle file** is loaded, NVS is reset to firmware defaults first, then `vehicleParams` is applied and saved. Use `CFG SAVE` after any further tuning to persist your customisations.

### Supported keys

| Key | Type | Range | `CFG SET` param | Description |
|-----|---|---|---|---|
| `steerScale` | integer | 1–20000 (unit x0.0001) | `steerScale` | Steering angle scale factor |
| `steerOffset` | integer | -500 to +500 | `steerOffset` | Steering centre offset |
| `steerInvert` | boolean | `true` / `false` | `steerInvert` | Reverse steering direction |
| `indTimeout` | integer | 100–2000 ms | `indTimeout` | Indicator blink detection timeout |
| `rpmDiv` | integer | 1–20 | `rpmDiv` | RPM raw value divisor |
| `tankCap` | integer | 20–100 L | `tankCap` | Fuel tank capacity in litres |
| `dteDiv` | integer | 100–500 | `dteDiv` | DTE divisor × 100 |

### Note on `rpmDiv`, `tankCap`, `dteDiv`

For most vehicles, these values are already encoded in the formula `params` of individual frame fields (e.g., `"params": [1, 7, 0]` for RPM). Setting them to `null` in `vehicleParams` avoids duplication and potential inconsistency. Define them here only if your vehicle requires a post-processing adjustment independent of the frame-level formula.

The steering parameters (`steerScale`, `steerOffset`, `steerInvert`) have **no frame-level equivalent** — they are applied during radio output in `RadioSend.cpp` and must be set here or via `CFG SET`.

### Lifecycle example

```
1. Load NissanJukeF15.json for the first time
   → NVS reset → steerScale=300, steerOffset=100, steerInvert=true applied and saved

2. Fine-tune via app: CFG SET steerScale 320, CFG SAVE
   → NVS now holds steerScale=320

3. Reboot — same vehicle file reloaded
   → vehicleParams NOT applied → NVS value 320 preserved ✓

4. Load a different vehicle (OtherVehicle.json)
   → NVS reset → OtherVehicle vehicleParams applied
```

---

## Targets

Variables that can be updated from CAN data:

### Numeric Values

| Target | Description | Unit |
|---|---|---|
| `STEERING` | Steering wheel angle | 0.1° |
| `ENGINE_RPM` | Engine speed | RPM |
| `VEHICLE_SPEED` | Speed | km/h |
| `FUEL_LEVEL` | Fuel in tank | Liters |
| `ODOMETER` | Total mileage | km |
| `VOLTAGE` | Battery voltage | 0.1V |
| `TEMPERATURE` | Temperature | °C |
| `DTE` | Distance to empty | km |
| `FUEL_CONS_INST` | Instant consumption | 0.1 L/100km |
| `FUEL_CONS_AVG` | Average consumption | 0.1 L/100km |

### Door Status (boolean)

| Target | Description |
|---|---|
| `DOOR_DRIVER` | Driver door open |
| `DOOR_PASSENGER` | Passenger door open |
| `DOOR_REAR_LEFT` | Rear left door open |
| `DOOR_REAR_RIGHT` | Rear right door open |
| `DOOR_BOOT` | Trunk/boot open |

### Lights (boolean)

| Target | Description |
|---|---|
| `INDICATOR_LEFT` | Left turn signal |
| `INDICATOR_RIGHT` | Right turn signal |
| `HEADLIGHTS` | Low beam |
| `HIGH_BEAM` | High beam |
| `PARKING_LIGHTS` | Parking lights |

---

## Data Types

| Type | Size | Range | Use Case |
|---|---|---|---|
| `UINT8` | 1 byte | 0 to 255 | Fuel level, voltage, temp |
| `INT8` | 1 byte | -128 to 127 | Signed single byte |
| `UINT16` | 2 bytes | 0 to 65535 | RPM, speed |
| `INT16` | 2 bytes | -32768 to 32767 | Steering angle |
| `UINT24` | 3 bytes | 0 to 16M | Odometer |
| `UINT32` | 4 bytes | 0 to 4B | Large values |
| `BITMASK` | variable | - | Extract specific bits |

---

## Formulas

### NONE

No conversion, use raw value as-is.

```json
"formula": "NONE"
```

### SCALE

Linear conversion: `result = (value × mult ÷ div) + offset`

```json
"formula": "SCALE",
"params": [mult, div, offset]
```

**Examples:**

```json
// RPM: raw / 7
"params": [1, 7, 0]

// Speed: raw / 100
"params": [1, 100, 0]

// Temperature: raw - 40
"params": [1, 1, -40]

// DTE: raw × 100 / 283
"params": [100, 283, 0]
```

### MAP_RANGE

Map value from one range to another: `map(value, inMin, inMax, outMin, outMax)`

```json
"formula": "MAP_RANGE",
"params": [inMin, inMax, outMin, outMax]
```

**Example:**

```json
// Fuel: 255=empty, 0=full → map to 0-45 liters
"params": [255, 0, 0, 45]
```

### BITMASK_EXTRACT

Extract specific bit(s): `result = (value & mask) >> shift`

```json
"formula": "BITMASK_EXTRACT",
"params": [mask, shift]
```

**Example:**

```json
// Extract bit 20 from 3-byte value (door status)
"params": [1048576, 20]
// 1048576 = 0x100000 = bit 20
```

---

## Byte Order

| Value | Description | Common In |
|---|---|---|
| `BE` | Big Endian (MSB first) | Most vehicles (Nissan, Toyota...) |
| `LE` | Little Endian (LSB first) | Some European cars |

**Example:** Value `0x1234` in 2 bytes

- Big Endian: `[0x12, 0x34]`
- Little Endian: `[0x34, 0x12]`

---

## Complete Example

Nissan Juke F15 - Engine RPM from CAN ID 0x180:

```
CAN Frame 0x180: [0x44, 0x7E, 0x00, 0x00, 0x00, 0x00, 0x00, 0x00]
                  ^^^^  ^^^^
                  Bytes 0-1 = 0x447E = 17534 (raw)

RPM = 17534 / 7 = 2504 RPM
```

```json
{
  "canId": "0x180",
  "fields": [
    {
      "target": "ENGINE_RPM",
      "startByte": 0,
      "byteCount": 2,
      "byteOrder": "BE",
      "dataType": "UINT16",
      "formula": "SCALE",
      "params": [1, 7, 0]
    }
  ]
}
```

---

## How to Find CAN Data for Your Vehicle

### 1. Online Resources

- **OpenDBC** (Comma.ai): https://github.com/commaai/opendbc
- **Car Hacking Wiki**: Various vehicle databases
- **Forums**: Vehicle-specific communities often have CAN documentation

### 2. Sniff Your CAN Bus

Tools needed:
- USB-CAN adapter (ELM327, Arduino + MCP2515, etc.)
- Software: SavvyCAN, can-utils, or similar

Process:
1. Connect to OBD-II port (pins 6=CAN-H, 14=CAN-L)
2. Record CAN traffic while changing vehicle state
3. Identify which CAN ID changes when you:
   - Rev the engine → RPM
   - Open a door → Door status
   - Turn the wheel → Steering angle
   - etc.

### 3. Decode the Data

1. Isolate the CAN ID
2. Determine byte position and count
3. Figure out byte order (try BE first)
4. Find the conversion formula (compare raw vs real value)

---

## Testing Your Preset

### 1. Upload to Device

Use the Android app or serial commands:

```
CAN UPLOAD START <filename> <size>
CAN UPLOAD DATA <base64_chunk>
CAN UPLOAD END
CAN LOAD <filename>
```

### 2. Check Data

```
SYS DATA
```

Shows current values for all fields.

### 3. Enable Logging

```
LOG ON
```

Shows raw CAN frames being processed.

---

## Tips

- Start with just RPM or speed to validate your setup
- Most vehicles use Big Endian byte order
- Door/light status are usually bitmasks in a single frame
- Steering angle is often signed (INT16)
- If values seem wrong, try swapping byte order
- Use `isMock: true` to test without a vehicle

---

## Contributing

Found CAN data for your vehicle? Share your preset:

1. Create a JSON file named `MakeModelYear.json`
2. Test thoroughly
3. Submit to the community presets repository

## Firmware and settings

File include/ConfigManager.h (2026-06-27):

/**
 * @file ConfigManager.h
 * @brief Persistent configuration storage using ESP32 NVS (Preferences)
 *
 * Stores vehicle-specific calibration values in non-volatile storage.
 * Values persist across reboots. Use configReset() to restore defaults.
 */

#ifndef CONFIG_MANAGER_H
#define CONFIG_MANAGER_H

#include <stdint.h>

// =============================================================================
// DEFAULT VALUES (Nissan Juke F15)
// =============================================================================

#define DEFAULT_STEER_OFFSET        100     // Center offset for steering
#define DEFAULT_STEER_INVERT        true    // Invert steering direction
#define DEFAULT_STEER_SCALE         300     // Scale (300 = 0.0300x, unit x0.0001)
#define DEFAULT_INDICATOR_TIMEOUT   500     // Indicator timeout in ms
#define DEFAULT_RPM_DIVISOR         7       // RPM = raw_value / 7
#define DEFAULT_TANK_CAPACITY       45      // Tank size in liters
#define DEFAULT_DTE_DIVISOR         283     // DTE = raw * 100 / 283

// =============================================================================
// CONFIGURATION STRUCTURE
// =============================================================================

struct CanboxConfig {
    int16_t  steerOffset;       // Steering center offset (-500 to +500)
    bool     steerInvert;       // Invert steering direction
    uint16_t steerScale;        // Scale factor (1-20000, represents 0.0001x to 2.0x)
    uint16_t indicatorTimeout;  // Indicator off timeout in ms
    uint8_t  rpmDivisor;        // RPM divisor (typically 7)
    uint8_t  tankCapacity;      // Fuel tank capacity in liters
    uint16_t dteDivisor;        // DTE divisor * 100 (283 = 2.83)
};

// =============================================================================
// PUBLIC API
// =============================================================================

/**
 * @brief Initialize and load configuration from NVS
 * Call once in setup(). Loads saved values or defaults if first boot.
 */
void configInit();

/**
 * @brief Save all current config values to NVS
 * Call after modifying config values to persist them.
 */
void configSave();

/**
 * @brief Reset all config values to defaults and save to NVS
 */
void configReset();

/**
 * @brief Get pointer to current config (read-only access)
 */
const CanboxConfig* configGet();

// =============================================================================
// INDIVIDUAL GETTERS (for convenience)
// =============================================================================

int16_t  configGetSteerOffset();
bool     configGetSteerInvert();
uint16_t configGetSteerScale();
uint16_t configGetIndicatorTimeout();
uint8_t  configGetRpmDivisor();
uint8_t  configGetTankCapacity();
uint16_t configGetDteDivisor();

// =============================================================================
// INDIVIDUAL SETTERS (automatically marks config as dirty, call configSave() to persist)
// =============================================================================

void configSetSteerOffset(int16_t value);
void configSetSteerInvert(bool value);
void configSetSteerScale(uint16_t value);
void configSetIndicatorTimeout(uint16_t value);
void configSetRpmDivisor(uint8_t value);
void configSetTankCapacity(uint8_t value);
void configSetDteDivisor(uint16_t value);

// =============================================================================
// VEHICLE CONFIG FILE (stored separately from calibration)
// =============================================================================

/**
 * @brief Get the last loaded vehicle config filename
 * @return Filename (e.g., "NissanJukeF15.json") or empty string if none saved
 */
const char* configGetVehicleFile();

/**
 * @brief Save the vehicle config filename to NVS
 * @param filename The filename to save (without leading /)
 */
void configSetVehicleFile(const char* filename);

#endif // CONFIG_MANAGER_H

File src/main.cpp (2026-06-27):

/**
 * @file main.cpp
 * @brief ESP32 CAN Gateway for Nissan Juke F15 to Android head unit
 *
 * This firmware acts as a bridge between the Nissan Juke F15 CAN bus and an
 * aftermarket Android head unit using Toyota RAV4 protocol. It reads vehicle data
 * from the OBD-II CAN bus and translates it to the format expected by the radio.
 *
 * Hardware: ESP32-C3 (or compatible) with TWAI CAN controller
 * CAN Speed: 500 kbps (Nissan standard)
 * Radio Protocol: Toyota RAV4 UART @ 38400 baud (Analysis by Mikescotland)
 */

#include <Arduino.h>
#include <ESP32-TWAI-CAN.hpp>
#include <esp_task_wdt.h>
#include <freertos/task.h>
#include "GlobalData.h"
#include "ConfigManager.h"
#include "SerialCommand.h"
#include "CanCapture.h"
#include "RadioSend.h"
#include "CanConfigProcessor.h"
#include "MockDataGenerator.h"

// ==============================================================================
// SAFETY CONFIGURATION
// ==============================================================================
#define WDT_TIMEOUT 5       // Hardware watchdog timeout in seconds (triggers panic on CPU hang)
#define CAN_TIMEOUT 30000   // 30s without CAN messages triggers reboot (if ignition is on)
#define MAX_CAN_ERRORS 100  // Max error count before emergency reset (CAN passive threshold ~127)

// ==============================================================================
// HARDWARE PIN CONFIGURATION
// ==============================================================================
#define CAN_TX 21
#define CAN_RX 20

// ==============================================================================
// GLOBAL VARIABLES
// ==============================================================================
uint32_t lastCanMessageTime = 0;
HardwareSerial RadioSerial(1);

// Configurable CAN processor and mock data generator
CanConfigProcessor canProcessor;
MockDataGenerator mockGenerator;

/**
 * @brief System initialization
 *
 * Initializes all hardware peripherals in the following order:
 * A. Status LED
 * B. Debug Serial
 * C. Configuration (NVS)
 * D. Serial Command Interface
 * E. Hardware Watchdog
 * F. Radio UART
 * G. CAN Configuration (JSON or Mock)
 * H. CAN Controller (if real mode)
 */
void setup() {
    // A. Status LED - Used for boot indication and heartbeat
    pinMode(8, OUTPUT);
    digitalWrite(8, HIGH); // LED ON = Boot in progress

    // B. Debug Serial - For monitoring via USB
    Serial.begin(115200);
    delay(2000);
    Serial.println("--- ESP32 BOOT (F15 Gateway) ---");

    // C. Load configuration from NVS (or use defaults on first boot)
    configInit();
    Serial.println("Config loaded");

    // D. Initialize serial command interface
    serialCommandInit();

    // E. Hardware Watchdog - Automatic reboot on system hang
    esp_task_wdt_deinit();
    esp_task_wdt_config_t twdt_config = {
        .timeout_ms = WDT_TIMEOUT * 1000,
        .idle_core_mask = (1 << 0),
        .trigger_panic = true,
    };
    esp_task_wdt_init(&twdt_config);
    esp_task_wdt_add(NULL);

    // F. Radio UART - Communication with Android head unit
    // TX=GPIO5, RX=GPIO6, 38400 baud, 8N1 (Toyota RAV4 protocol)
    RadioSerial.begin(38400, SERIAL_8N1, 6, 5);

    // G. CAN Configuration - Load from JSON or use mock mode
    canProcessor.begin();  // Attempts to load /vehicle.json or /NissanJukeF15.json

    if (canProcessor.isMockMode()) {
        Serial.println("=== MOCK MODE ACTIVE ===");
        Serial.println("No vehicle config found - using simulated data");
        mockGenerator.begin();
        // Skip CAN hardware initialization in mock mode
    } else {
        Serial.printf("Vehicle config loaded: %s\n", canProcessor.getProfileName());

        // H. CAN Bus Initialization - TWAI controller setup (only in real mode)
        ESP32Can.setPins(CAN_TX, CAN_RX);
        ESP32Can.setSpeed(ESP32Can.convertSpeed(500000)); // 500kbps (Nissan Juke standard)

        // Attempt CAN startup with immediate error handling
        if (!ESP32Can.begin()) {
            Serial.println("CRITICAL ERROR: CAN INIT FAILED -> Reboot in 3s");
            delay(3000);
            ESP.restart();
        } else {
            Serial.println("CAN OK");
        }
    }

    lastCanMessageTime = millis();
    digitalWrite(8, LOW); // LED OFF = Boot complete
}

/**
 * @brief Main loop - Runs continuously after setup()
 *
 * Execution flow:
 * 1. Feed the watchdog
 * 2. Process serial commands
 * 3. Mode-dependent data acquisition (mock or real CAN)
 * 4. Send updates to the radio
 */
void loop() {
    unsigned long now = millis();
    esp_task_wdt_reset(); // Feed the watchdog to prevent system reset

    // Process serial commands (non-blocking)
    serialCommandProcess();

    // ==========================================================================
    // MODE-DEPENDENT DATA ACQUISITION
    // Skip during OTA for maximum throughput
    // ==========================================================================
    if (isOtaInProgress()) {
        serialCommandCheckOtaTimeout();
        vTaskDelay(pdMS_TO_TICKS(1));  // yield to USB CDC FreeRTOS tasks
        return;
    }

    if (canProcessor.isMockMode()) {
        // MOCK MODE: Generate simulated data
        mockGenerator.update();
        lastCanMessageTime = now;  // Prevent timeout in mock mode

        // Slow LED blink to indicate mock mode
        static unsigned long lastMockBlink = 0;
        if (now - lastMockBlink > 500) {
            digitalWrite(8, !digitalRead(8));
            lastMockBlink = now;
        }
    } else {
        // REAL MODE: Read from CAN bus
        CanFrame rxFrame;

        // CAN BUS ERROR MONITORING
        uint32_t rxErr = ESP32Can.rxErrorCounter();
        uint32_t busErr = ESP32Can.busErrCounter();

        if (isCanLogEnabled() && (rxErr > 0 || busErr > 0)) {
            Serial.printf("Errors RX: %d | Bus: %d | State: %d\n",
                          rxErr, busErr, ESP32Can.canState());
        }

        if (rxErr > MAX_CAN_ERRORS || busErr > MAX_CAN_ERRORS || ESP32Can.canState() == TWAI_STATE_BUS_OFF) {
            Serial.printf("\n!!! CAN BUS CRASH DETECTED !!!\n");
            Serial.printf("RX Err: %d | Bus Err: %d | State: %d\n", rxErr, busErr, ESP32Can.canState());
            Serial.println("-> EMERGENCY CONTROLLER RESET...");
            delay(100);
            ESP.restart();
        }

        // CAN BUS READING
        if (ESP32Can.readFrame(rxFrame)) {
            handleCanCapture(rxFrame);
            lastCanMessageTime = now;
        } else {
            // Slow heartbeat when no messages (indicates silent bus)
            static unsigned long lastHeartbeat = 0;
            if (now - lastCanMessageTime > 200 && now - lastHeartbeat > 1000) {
                digitalWrite(8, !digitalRead(8));
                lastHeartbeat = now;
            }
        }

        // SAFETY: GLOBAL TIMEOUT (Engine off or wire disconnected)
        if (now - lastCanMessageTime > CAN_TIMEOUT && voltBat > 11.0) {
            Serial.println("CAN SILENCE TIMEOUT -> SAFETY REBOOT");
            delay(100);
            ESP.restart();
        }
    }

    // ==========================================================================
    // RADIO TRANSMISSION (both modes)
    // ==========================================================================
    processRadioUpdates();
}

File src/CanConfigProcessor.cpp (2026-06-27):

/**
 * @file CanConfigProcessor.cpp
 * @brief Implementation of configurable CAN frame processor
 *
 * This module loads vehicle configuration from JSON files and uses it to
 * decode CAN frames into GlobalData variables. It provides flexibility to
 * support multiple vehicles without code changes.
 *
 * JSON Configuration Loading:
 * 1. Mount LittleFS filesystem
 * 2. Search for config files (/vehicle.json, /NissanJukeF15.json)
 * 3. Parse JSON using ArduinoJson
 * 4. Build internal VehicleProfile structure
 *
 * Frame Processing:
 * 1. Look up CAN ID in configuration
 * 2. For each field in the frame config:
 *    a. Extract raw bytes according to startByte, byteCount, byteOrder
 *    b. Apply conversion formula (SCALE, MAP_RANGE, BITMASK_EXTRACT)
 *    c. Write result to appropriate GlobalData variable
 */

#include "CanConfigProcessor.h"
#include "GlobalData.h"
#include "ConfigManager.h"
#include <LittleFS.h>
#include <ArduinoJson.h>

// =============================================================================
// CONSTRUCTOR
// =============================================================================

CanConfigProcessor::CanConfigProcessor()
    : _mockMode(true)           // Default to mock until config loaded
    , _framesProcessed(0)
    , _unknownFrames(0)
{
}

// =============================================================================
// INITIALIZATION
// =============================================================================

/**
 * @brief Initialize processor and load configuration from SPIFFS
 *
 * Attempts to load configuration from known file paths.
 * If no config found, falls back to mock mode.
 */
bool CanConfigProcessor::begin() {
    // Initialize LittleFS filesystem
    if (!LittleFS.begin(true)) {
        Serial.println("[CanConfig] LittleFS mount failed");
        _mockMode = true;
        return false;
    }

    // Check if a previously loaded config is saved in NVS
    const char* savedFile = configGetVehicleFile();
    if (savedFile[0] != '\0') {
        char savedPath[48];
        snprintf(savedPath, sizeof(savedPath), "/%s", savedFile);
        if (LittleFS.exists(savedPath)) {
            Serial.printf("[CanConfig] Restoring saved config: %s\n", savedPath);
            if (loadFromJson(savedPath)) {
                Serial.printf("[CanConfig] Loaded: %s (%d frames) - %s mode\n",
                              _profile.name.c_str(),
                              _profile.frames.size(),
                              _mockMode ? "MOCK" : "REAL CAN");
                return true;
            }
        }
    }

    // Fallback: Configuration file search order
    const char* configPaths[] = {
        "/vehicle.json",        // Primary: generic name for current vehicle
        "/MockDemo.json",       // Default: mock mode for testing
        "/NissanJukeF15.json"   // Fallback: specific vehicle config
    };

    // Try each config path until one succeeds
    for (const char* path : configPaths) {
        if (LittleFS.exists(path)) {
            Serial.printf("[CanConfig] Found config: %s\n", path);
            if (loadFromJson(path)) {
                Serial.printf("[CanConfig] Loaded: %s (%d frames) - %s mode\n",
                              _profile.name.c_str(),
                              _profile.frames.size(),
                              _mockMode ? "MOCK" : "REAL CAN");
                return true;
            }
        }
    }

    // No config found - use mock mode with simulated data
    Serial.println("[CanConfig] No config found - MOCK mode active (default)");
    _mockMode = true;
    return false;
}

// =============================================================================
// JSON CONFIGURATION LOADING
// =============================================================================
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

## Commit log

2026-01-04 Initial commit: Nissan Juke CAN gateway with ESP32-C3
2026-01-12 Fix: Linker errors, WDT init for ESP32 v3.0, and C3 Serial/CAN conflict
    [main.cpp]
2026-01-12 Feat: Add LED status patterns (Strobe on Error, Heartbeat on Idle, Flash on Data)
    [main.cpp]
2026-01-12 Docs: Update pinout and LED status codes
2026-01-18 Feat: Can communicate with my headunit (duduOS FYT) only with the polo canbus
2026-01-18 Fix: wrong format data read/send (speed, rpm, fuel, steering, ...)
    [CanCapture.cpp, RadioSend.cpp]
2026-01-18 Feat: Improve stability when we start the car (reboot the control when there are to many can error)
    [main.cpp]
2026-01-18 Fix: wrong format data read/send (again speed, rpm, fuel, steering, ...)
    [CanCapture.cpp, RadioSend.cpp, main.cpp]
2026-01-18 Fix: calibrate steering angle range for dynamic guidelines
    [RadioSend.cpp]
2026-01-18 Fix: correct door mapping (0x60D) and move trunk detection to byte 3
    [CanCapture.cpp]
2026-01-18 docs: add wiring schematic (thanks Polihedron)
2026-01-18 docs: fix documentation to match calibrated code
    [CanCapture.cpp]
2026-01-20 docs: improve power supply documentation with 12V warnings
    - Clarify USB power is recommended over 12V
    - Add warning to never use permanent 12V (battery drain risk)
    - Specify ACC (accessory) 12V must be used if not using USB
    - Note current 12V circuit lacks reverse polarity protection
    - Note current 12V circuit lacks proper noise filtering for alternator interference
    - Explain automotive 12V instability (voltage drops, spikes, noise)
2026-01-20 docs: add Nissan Juke F15 service manuals (via Git LFS)
    - Add 57 official Nissan service manual PDFs (~79MB total)
    - Configure Git LFS for docs/vehicle/**/*.pdf
    - Add comprehensive README with categorized manual index
    - Archive from NICOclub for reference and preservation
    - Key docs: LAN.pdf (CAN bus), BCS.pdf (body control)
2026-01-20 feat: add serial CAN injection for testing without vehicle
    - Add serial command parser in main.cpp to inject CAN frames via USB
    - Format: >ID DATA (e.g., >180 04 FB 36 23 4C 00 36 00)
    - Supports hex IDs with/without 0x prefix, spaces in data optional
    - Add tools/can_inject.py script to replay CAN captures
    - Add sample CAN capture data for testing
    - Add tools/README.md with usage documentation
2026-01-20 docs: fix technical documentation to match code and Raise v1.4 spec
    RADIO_SEND.md:
    - Fix checksum formula: XOR 0xFF instead of subtraction
    - Fix dashboard data: Big Endian for speed, add odometer bytes 9-11
    - Fix door status: 2 bytes (not 13), add bits 5-7 for handbrake/washer/seatbelt
    - Fix handshake: 0x81 start/end with ACK, remove incorrect 0xC0/0xF1 references
    CAN_CAPTURE.md:
    - Fix door bit mapping: bit 4 (0x10) = Driver, bit 3 (0x08) = Passenger
2026-01-20 feat: add 3D printable enclosure for canbox
    Adds canbox-enclosure.3mf for protecting the ESP32 PCB and electronics
    [canbox-enclosure.3mf]
2026-01-21 feat: complete Raise toyota rav4 protocol v1.4 with lights, indicators and config
    - Add indicators and lights decoding from CAN frame 0x60D
    - Add Config.h for user-calibratable steering parameters
    - Implement Toyota RAV4 protocol frame format in RadioSend
    - Update documentation to match new status word bit mapping
2026-01-21 chore: cleanup code for v1.5 pre-release
    - Remove commented debug logging from CanCapture.cpp
    - Remove alternative fuel consumption code (0x358)
    - Fix comment: VW Polo → Toyota RAV4 protocol
    - Update debug logging example in docs
    [CanCapture.cpp, main.cpp]
2026-01-21 feat: add ConfigManager with NVS persistent storage (Phase 2.1)
    Replace hardcoded #define constants with runtime-configurable values
    stored in ESP32 NVS (non-volatile storage).
    New files:
    - include/ConfigManager.h: API and default values
    - src/ConfigManager.cpp: NVS read/write implementation
    Configurable parameters:
    - steerOffset: Steering center offset (default: 100)
    - steerInvert: Invert steering direction (default: true)
    - steerScale: Steering scale factor (default: 4)
    - indicatorTimeout: Indicator off timeout in ms (default: 500)
    - rpmDivisor: RPM calculation divisor (default: 7)
    - tankCapacity: Fuel tank size in liters (default: 45)
    - dteDivisor: Distance-to-empty divisor (default: 28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
    [CanCapture.cpp, ConfigManager.h, RadioSend.cpp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]
2026-01-22 feat: add serial command interface for USB configuration (Phase 2.2)
    Implements AT-style command parser for runtime configuration via USB:
    - CFG GET/SET/LIST/SAVE/RESET for configuration management
    - LOG ON/OFF for CAN frame debugging
    - SYS INFO/DATA/REBOOT for system control
    [SerialCommand.cpp, main.cpp]
2026-01-24 docs: add project on hold notice (waiting for ESP32)
2026-01-25 feat: add configurable CAN system with JSON configs and USB upload
    - Add CanConfigProcessor for JSON-based CAN frame decoding
    - Add MockDataGenerator for simulated vehicle data (default mode)
    - Add VehicleConfig.h with data structures and enums
    - Add NissanJukeF15.json vehicle configuration
    - Add CAN serial commands (STATUS, LIST, LOAD, GET, DELETE, UPLOAD, RELOAD)
    - Add USB serial protocol documentation
    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
2026-01-25 docs: update roadmap and READMEs for V2 features
    - Update ROADMAP.md with completed phases 2.1-2.3
    - Add USB Configuration section to README.md and README.fr.md
    - Add Multi-Vehicle Support documentation
    - Update LED status codes with Mock Mode pattern
    - Update Software Architecture section
2026-01-25 feat: add OTA firmware update via USB serial (Phase 2.4)
    Implement complete OTA firmware update protocol over USB serial:
    - OTA START <size> [md5] - initiate firmware update with optional MD5
    - OTA DATA <base64> - receive base64-encoded firmware chunks
    - OTA END - finalize update, verify MD5, auto-reboot
    - OTA ABORT - cancel in-progress update
    - OTA STATUS - show update progress and available space
    Features:
    - Uses native ESP32 Update.h library
    - Optional MD5 verification for firmware integrity
    - Progress reporting with percentage
    - Automatic 2-second delay before reboot
    - Comprehensive error handling
    Bump version to 1.7.0
    [SerialCommand.cpp]
2026-01-25 feat: add SYS BOOTLOADER command for fast esptool flashing
    Add SYS BOOTLOADER command that forces ESP32 into ROM bootloader mode
    for fast firmware updates using esptool protocol (~100+ KB/s).
    This is the recommended method for firmware updates from Android app.
    The OTA serial commands (base64) remain as a fallback option.
    Usage:
    > SYS BOOTLOADER
    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
2026-01-25 docs: add link to companion Android app
    Add "Companion App" section in both READMEs linking to the new
    esp32-canbox-manager Android repository.
2026-01-28 feat: add config file persistence and mock mode improvements
    - Save selected vehicle config filename to NVS for auto-restore on boot
    - Allow mock configs with empty frames array (uses simulated data)
    - Update _mockMode flag in loadFromJson() for proper mode switching
    - Display config filename in CAN STATUS and SYS DATA commands
2026-01-28 docs: add OTA protocol documentation for app integration
    - Add complete OTA protocol doc with sequence diagrams and Kotlin example
    - Revert to stable OTA v1 (base64 mode, ~40 KB/s)
    - Update firmware version to 1.7.1
    - Add MockDemo.json to config search order
    [CanConfigProcessor.cpp]
2026-01-28 fix: CAN GET now returns currently loaded config file
    [SerialCommand.cpp]
2026-01-28 fix: increase command buffer size to 320 bytes for reliable uploads
    - CMD_BUFFER_SIZE increased from 256 to 320 bytes to prevent base64
    data truncation during CAN config and OTA uploads
    - Add Serial.flush() and delay(1) after ACK to ensure USB CDC transmits
    the response before processing next chunk
    - Add CAN_CONFIG_PROTOCOL.md documentation with complete protocol spec
    - Update OTA_PROTOCOL.md with correct buffer size
    [SerialCommand.cpp]
2026-01-28 feat: reset vehicle data when loading new CAN config
    Add resetVehicleData() function that clears all vehicle telemetry
    (RPM, speed, fuel, doors, lights, etc.) to default values. Called
    when CAN LOAD or CAN RELOAD commands succeed, preventing stale data
    from previous configuration being displayed.
    [SerialCommand.cpp]
2026-01-28 fix: skip CAN processing during OTA for maximum throughput
    - Add isOtaInProgress() to check OTA state from main loop
    - Skip CAN bus reading and mock data generation during OTA
    - Add Serial.flush() to otaData() for immediate ACK transmission
    This fixes slow OTA when using real CAN configs (like F15) where
    CAN processing was competing with OTA data transfer.
    [SerialCommand.cpp, main.cpp]
2026-01-30 docs: add passthrough architecture for external CANBox support
    - Update ROADMAP with v1.8 passthrough feature planned
    - Add PASSTHROUGH.md with architecture, wiring, and implementation notes
2026-01-31 docs: reorganize roadmap with v1.8 and v1.9 milestones
    - v1.8: Additional vehicle data (temp, fuel, DTE, recorder, auto-calibration)
    - v1.9: External CANBox passthrough
    - Note: Community presets handled by Android app
    - Change project name
2026-02-19 fix: prevent watchdog reset during slow flash operations
    - Add esp_task_wdt_reset() during OTA data reception and finalization
    - Add watchdog reset during CAN config file upload and LittleFS write
    - Include esp_task_wdt.h in SerialCommand.cpp
    This prevents accidental reboots during slow flash/filesystem operations
    where execution time can exceed the 5-second hardware watchdog timeout.
    [SerialCommand.cpp]
2026-06-27 feat: steerScale precision x0.0001 + OTA protocol hardening (v2) (#1)
    * refactor: change steerScale type to uint16 with x0.0001 unit
    Precision was limited to 0.01x steps (uint8, range 1-200), making values
    below 0.01x unreachable. Change to uint16 with unit x0.0001 (range 1-20000),
    allowing values as fine as 0.0001x (e.g. 200 = 0.0200x, 188 = 0.0188x).
    Default updated from 3 to 300 to preserve the same 0.0300x physical value.
    NVS storage changed from getUChar/putUChar to getUShort/putUShort.
    Note: on first boot after update, steerScale resets to default (300 = 0.030x).
    * fix: update steering formula divisor 100 to 10000
    Aligns with the new steerScale unit (x0.0001 per unit).
    No overflow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
    [CanConfigProcessor.cpp, ConfigManager.h, ConfigManager_mock.h]
2026-06-27 fix: align CRC32 to standard mode + fix native test failures
    - test/mocks/Arduino.h: replace #define max/min macros with
    'using std::max/min' in C++ mode to avoid GCC 13 STL conflict
    (stl_bvector.h template instantiation broken by function-like macros)
    - src/SerialCommand.cpp: use crc32_le(0xFFFFFFFF,...) ^ 0xFFFFFFFF
    to match java.util.zip.CRC32 and zlib.crc32 standard convention
    - test_ota_logic.cpp: fix base64 string 252→240 chars; update CRC32
    tests to use standard init=0xFFFFFFFF+XOR calling convention
    - test_ota_protocol.py: switch from binascii.crc32 to zlib.crc32
    [SerialCommand.cpp, test_ota_protocol.py]
2026-06-27 fix: revert CRC32 to init=0 matching Android app convention
    [SerialCommand.cpp]
2026-06-27 fix: restrict release build to esp32-c3-devkitm-1 env only
